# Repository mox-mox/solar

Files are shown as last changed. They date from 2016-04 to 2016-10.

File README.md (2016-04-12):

# solar

This repo will contain the files for a step-up converter board for powering my laptop from some solar cells.

Idea
====

Create a power supply that can power my laptop for off-grid use. To avoid having to re-charge the supply and avoid charge limits, use solar cells*. The panel should be foldable in some way to be portable when hiking.

*: Additional bonus: When I have to turn the display backlight higher on [very] bright days, the solar cells will also produce more energy.

Specification
-------------
Board:
 - Input: ca. 6-15V, up to 10A DC from solar cells or a battery AND 20V from a Thinkpad power plug*.
 - Output0: 20V, 2.5A OR 3.0A Voltage for Thinkpad
 - Output1: 5V, 1.5A for charging my mobile phone
 - Output2: 3.3V, 2A for supplying miscellaneous electronic devices [optional]
 - Output4: Battery charger for lead acid car starter battery [optional] AND/OR charging circuit for a lithium polymer battery.

Power supply:
 - Use 16 highly efficient soloar cells of 15 by 15 centimeters, yielding about 9V at 1 to 6A
 - The cell array should be foldable in some way to allow handy transportation in a backpack

Case:
 - The case should hold the converter board and provide a protected space for the solar cells for transportation
 - Target size is about 16 by 20 by 5 centimeters
 - Will probably be made of steel sheets for maximum protection

Connectors:
 - Power connector for the solar cells or battery
 - Thinkpad compatible receptable to attach a Thinkpad power plug.
 - Thinkpad compatible power plug to supply the Laptop
 - Some USB ports to charge USB-devices
 - A multi-plug with exchangable tips for all kinds of devices
 - Pinheaders providing 3.3V

*The 20V will be looped through with the voltage regulator for output0 disabled. This way, the board can still provide the low-voltage outputs.

Soldering QFN and VSON packages
-------------------------------
 - The outer QFN 'pins' can be soldered from the outside, pre-tinning the pads and using [lots of] flux
 - The bottom pad will be soldered from below, unsing the thermal vias that are anyways needed. For that purpose, the solder resist mask is removed from these vias.
 - See: https://www.youtube.com/watch?v=d-f-SBC0GrU

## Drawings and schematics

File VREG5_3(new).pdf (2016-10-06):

## WEBENCH ® Design Report

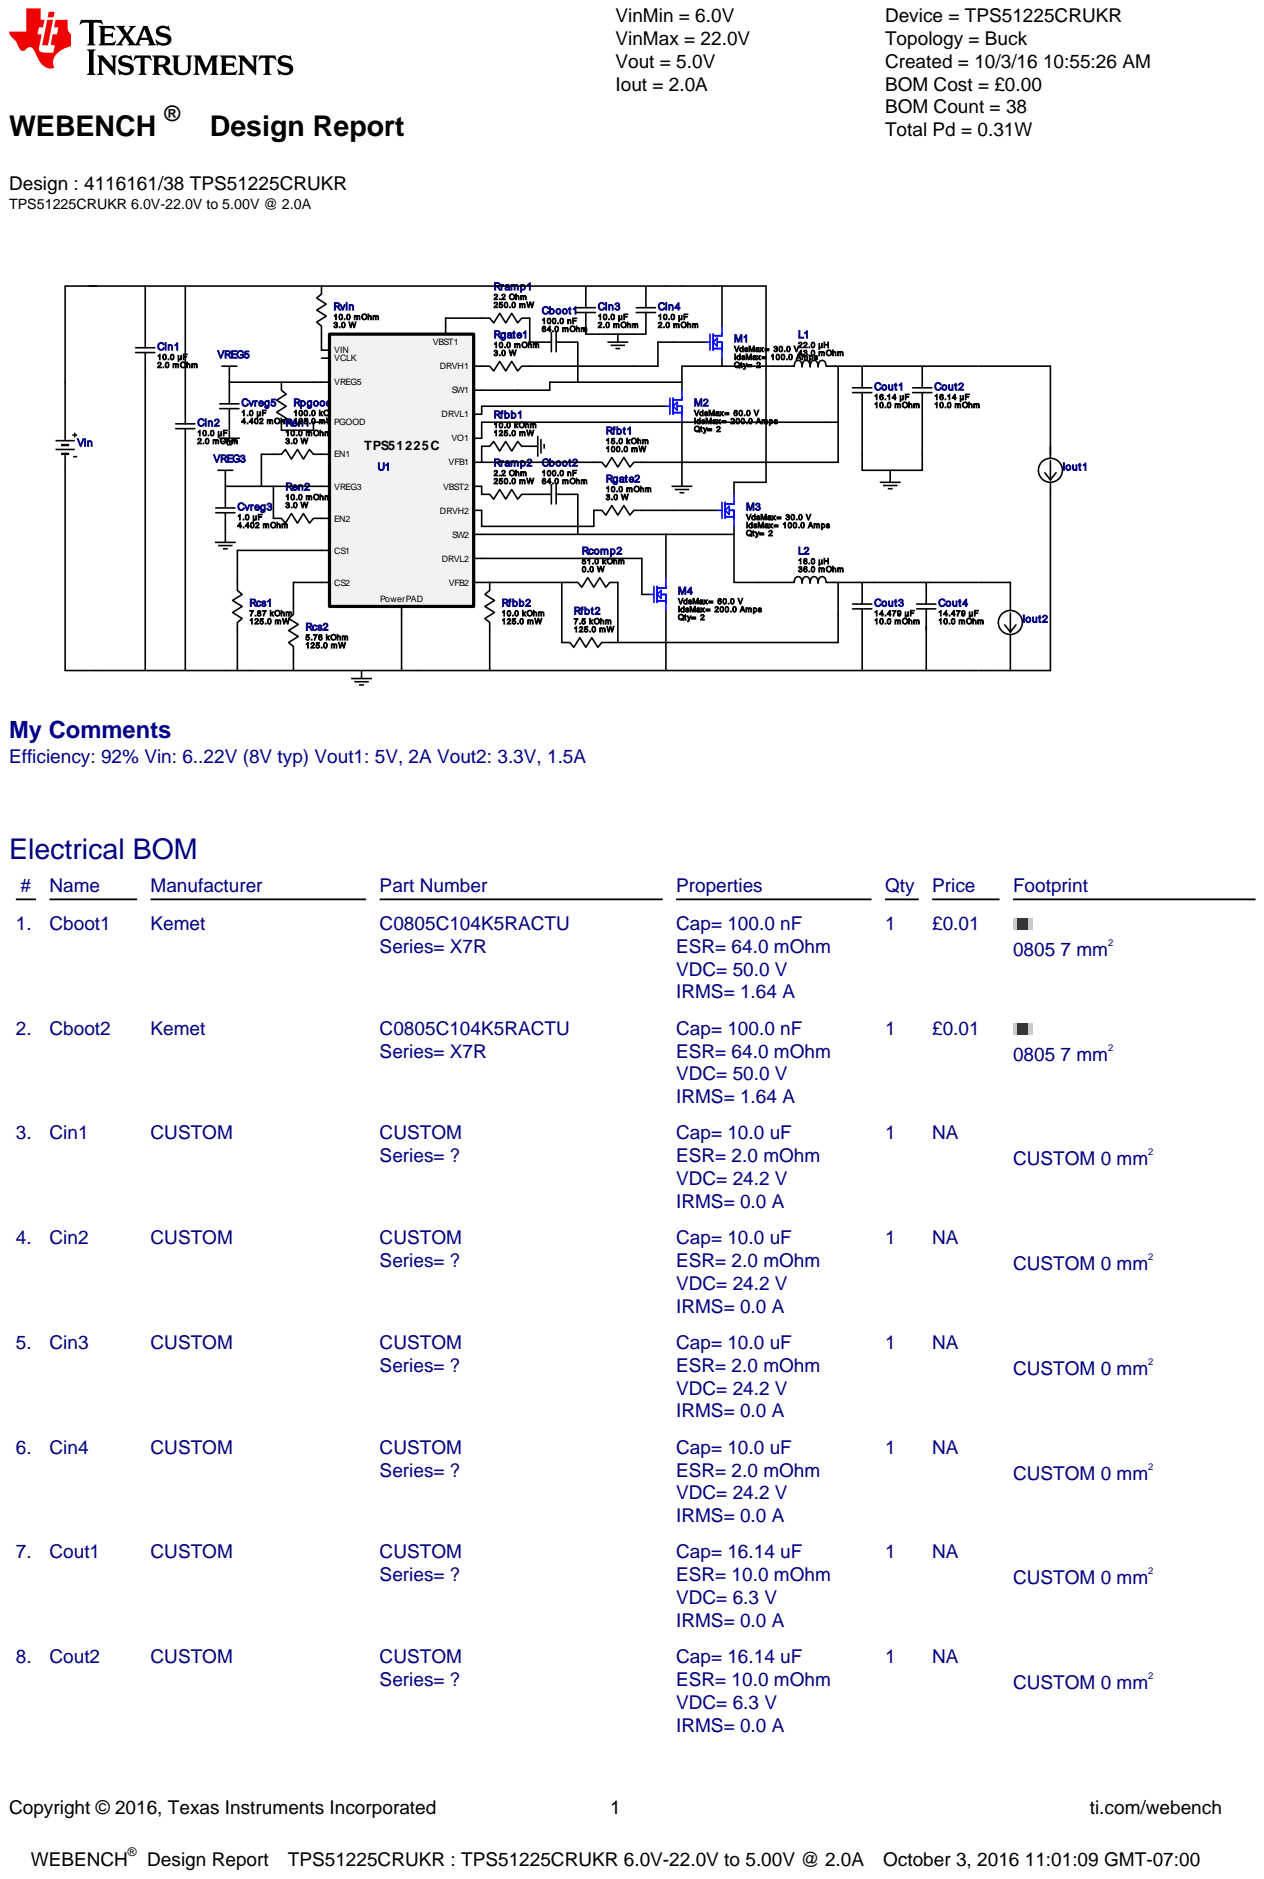
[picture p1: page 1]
Copyright © 2016, Texas Instruments Incorporated; ti.com/webench; WEBENCH®; Design : 4116161/38 TPS51225CRUKR TPS51225CRUKR 6.0V-22.0V to 5.00V @ 2.0A; VinMin = 6.0V VinMax = 22.0V Vout = 5.0V Iout = 2.0A; Device = TPS51225CRUKR Topology = Buck Created = 10/3/16 10:55:26 AM BOM Cost = £0.00 BOM Count = 38 Total Pd = 0.31W; Cboot1 100.0 nF 64.0 mOhm; Cboot2 100.0 nF 64.0 mOhm; Cin1 10.0 µF 2.0 mOhm; Cin2 10.0 µF 2.0 mOhm; Cin3 10.0 µF 2.0 mOhm; Cin4 10.0 µF 2.0 mOhm; Cout1 16.14 µF 10.0 mOhm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

My Comments
Efficiency: 92% Vin: 6..22V (8V typ) Vout1: 5V, 2A Vout2: 3.3V, 1.5A

Design Report TPS51225CRUKR : TPS51225CRUKR 6.0V-22.0V to 5.00V @ 2.0A October 3, 2016 11:01:09 GMT-07:00

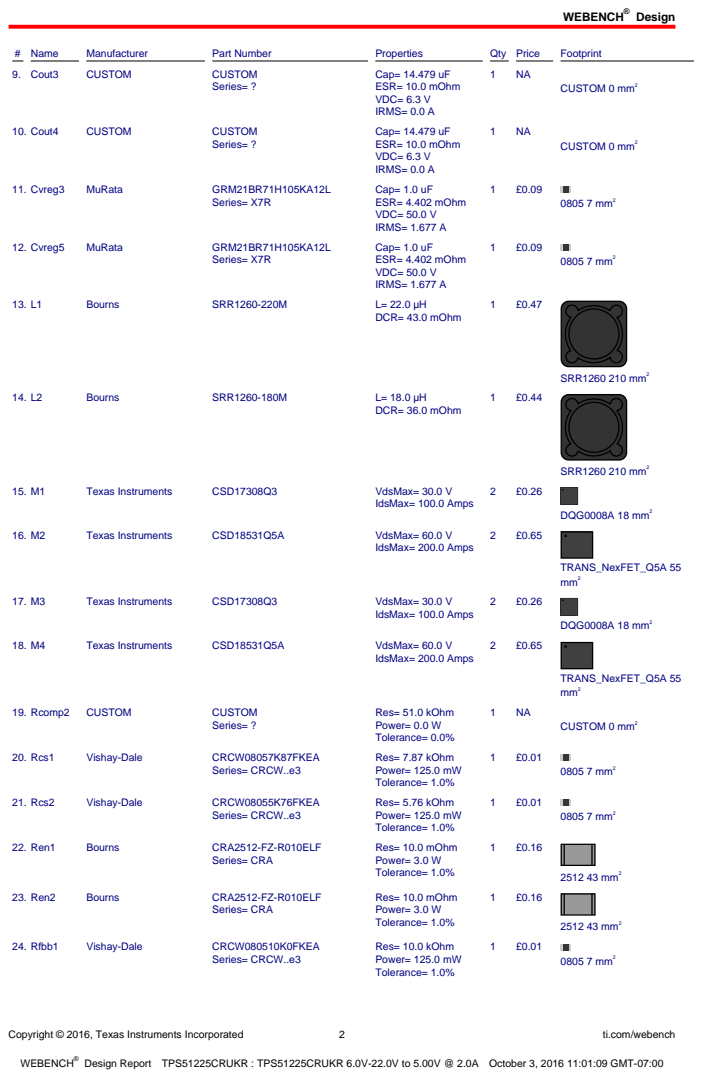
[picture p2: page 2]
Design; Copyright © 2016, Texas Instruments Incorporated; ti.com/webench; # Name; Manufacturer; Part Number; Properties; Qty Price; Footprint; 9. Cout3; CUSTOM; Series= ?; Cap= 14.479 uF ESR= 10.0 mOhm VDC= 6.3 V IRMS= 0.0 A; CUSTOM 0 mm²; 10. Cout4; 11. Cvreg3; MuRata; GRM21BR71H105KA12L; Series= X7R; Cap= 1.0 uF ESR= 4.402 mOhm VDC= 50.0 V IRMS= 1.677 A; 0805 7 mm²; 12. Cvreg5; Bourns; SRR1260-220M; DCR= 43.0 mOhm; SRR1260 210 mm²; SRR1260-180M; DCR= 36.0 mOhm; Texas Instruments; CSD17308Q3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

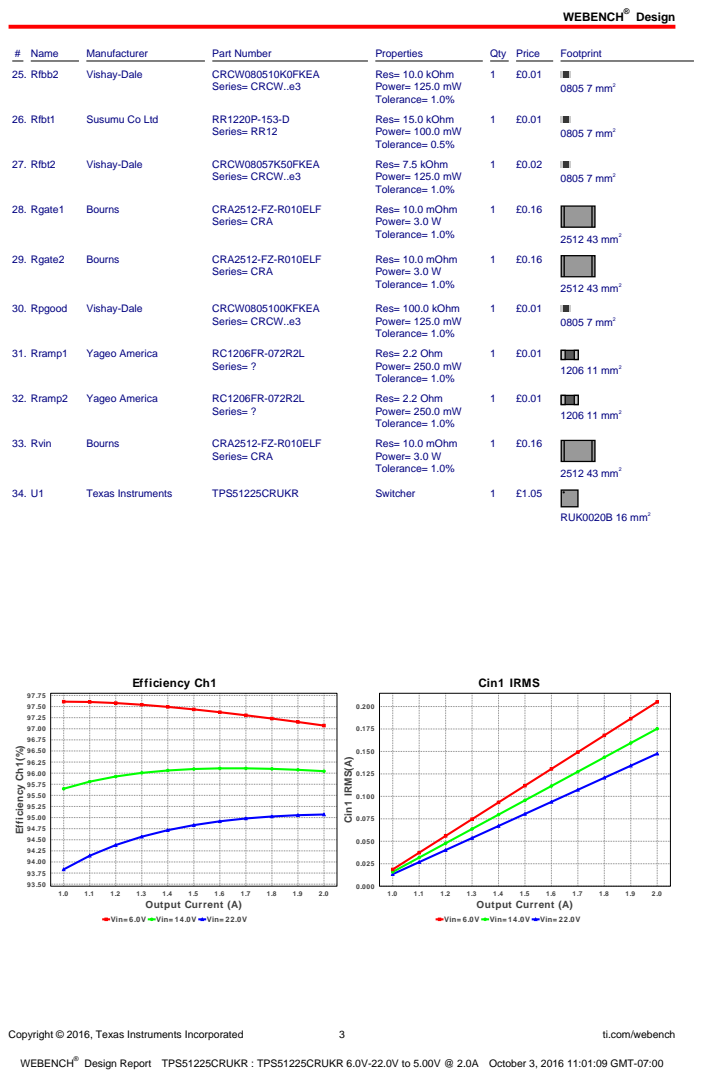
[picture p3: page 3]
Copyright © 2016, Texas Instruments Incorporated; ti.com/webench; # Name; Manufacturer; Part Number; Properties; Qty Price; Footprint; 25. Rfbb2; Vishay-Dale; CRCW080510K0FKEA; Series= CRCW..e3; Res= 10.0 kOhm Power= 125.0 mW Tolerance= 1.0%; 0805 7 mm²; 26. Rfbt1; Susumu Co Ltd; Series= RR12; Res= 15.0 kOhm Power= 100.0 mW Tolerance= 0.5%; 27. Rfbt2; CRCW08057K50FKEA; Res= 7.5 kOhm Power= 125.0 mW Tolerance= 1.0%; 28. Rgate1; Bourns; CRA2512-FZ-R010ELF; Series= CRA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

Vin= 6.0V Vin= 14.0V Vin= 22.0V

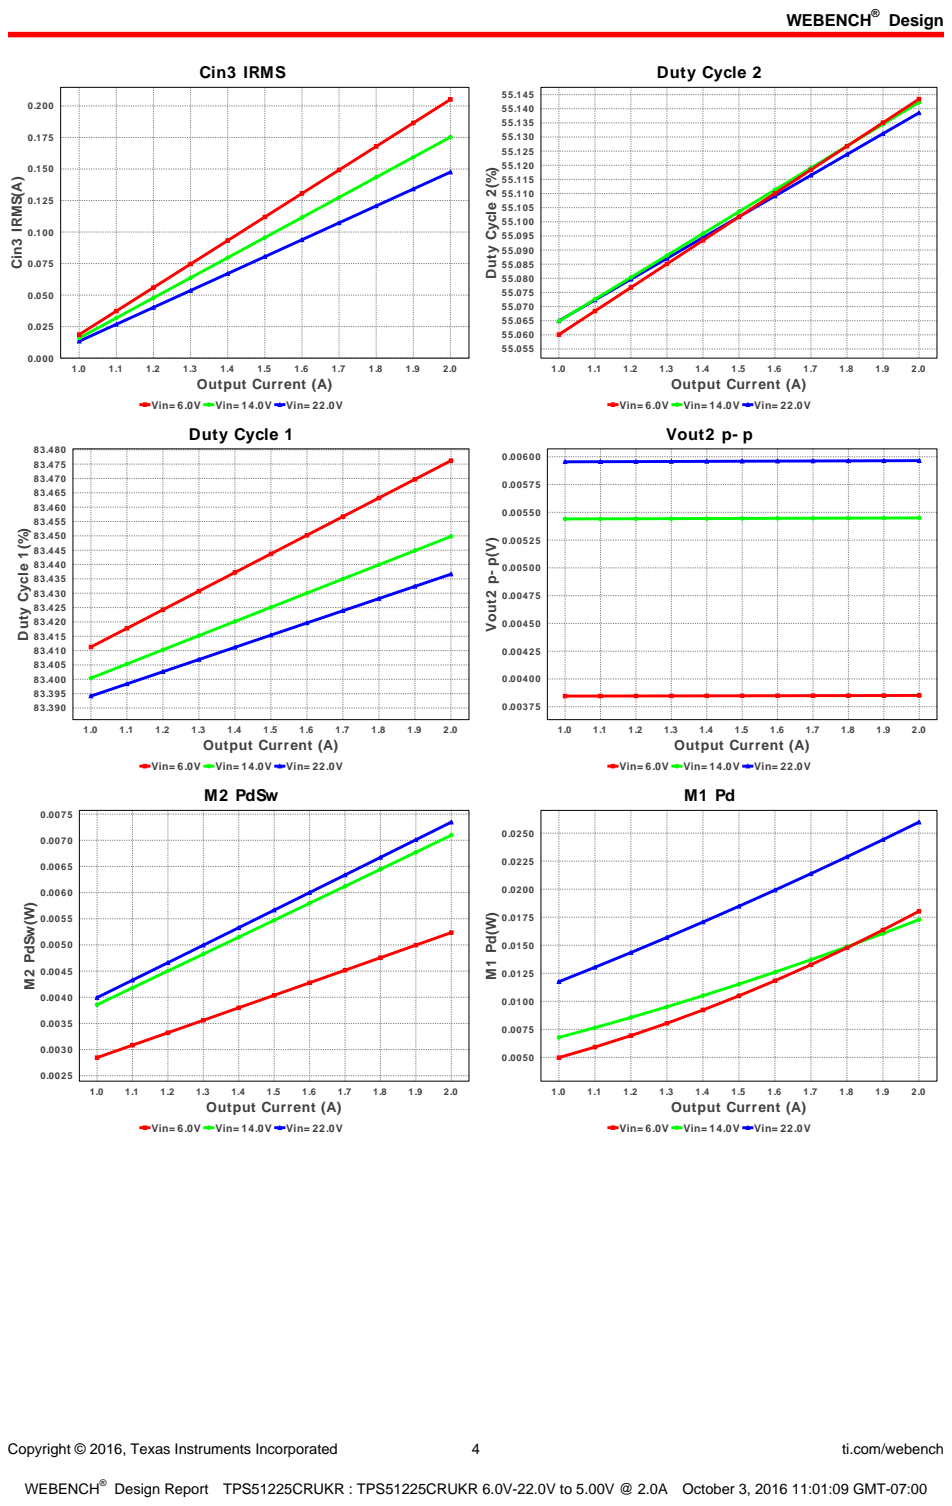
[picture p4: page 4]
Copyright © 2016, Texas Instruments Incorporated; ti.com/webench; Cin3 IRMS; 2.0 Output Current (A); Cin3 IRMS(A); Duty Cycle 2; Duty Cycle 2(%); Duty Cycle 1(%); Vout2 p- p(V); M2 PdSw(W)

Vin= 6.0V Vin= 14.0V Vin= 22.0V
Duty Cycle 1

Vout2 p- p

M2 PdSw

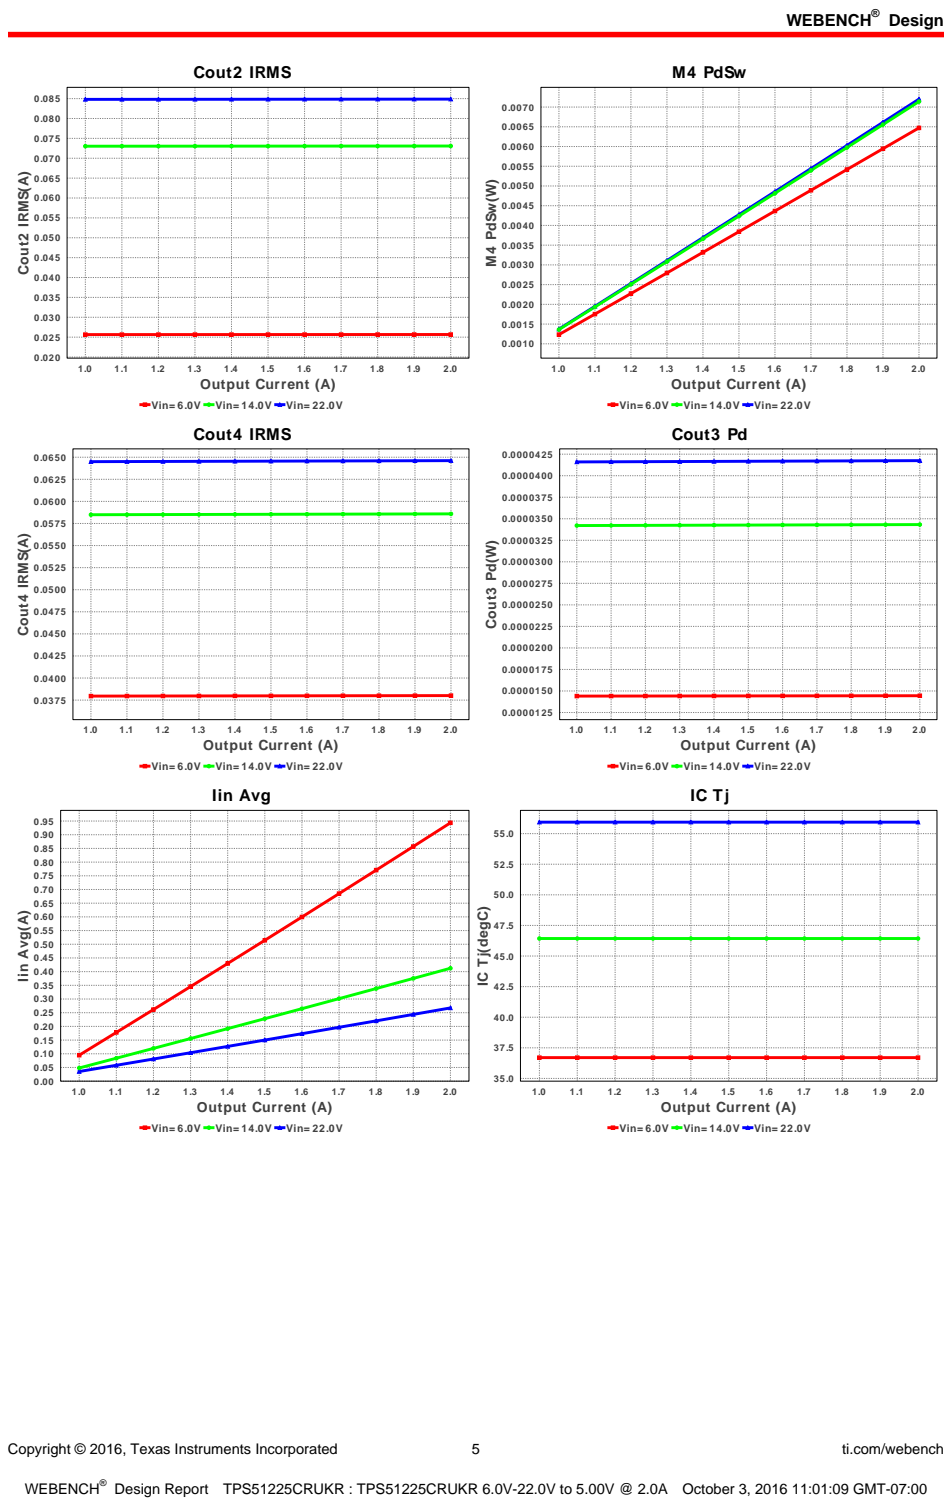
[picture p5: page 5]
Copyright © 2016, Texas Instruments Incorporated; ti.com/webench; Cout2 IRMS; 2.0 Output Current (A); Cout2 IRMS(A); M4 PdSw; M4 PdSw(W); Cout4 IRMS(A); Cout3 Pd(W); Iin Avg; Iin Avg(A)

Vin= 6.0V Vin= 14.0V Vin= 22.0V
Cout4 IRMS

Cout3 Pd

IC Tj(degC)

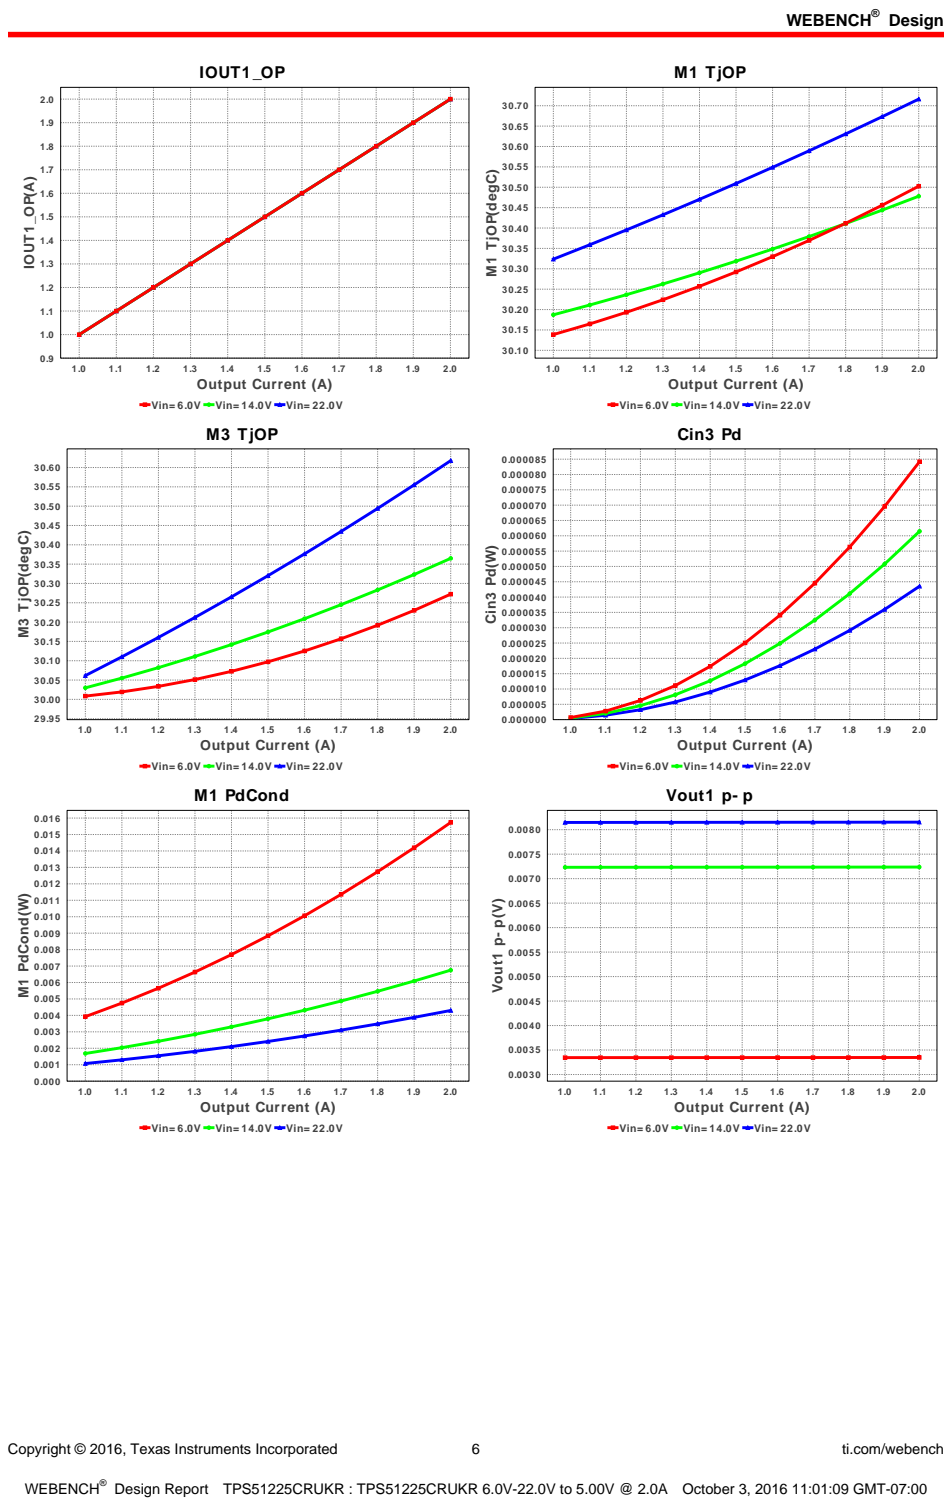
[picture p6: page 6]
Copyright © 2016, Texas Instruments Incorporated; ti.com/webench; IOUT1_OP; 2.0 Output Current (A); IOUT1_OP(A); M1 TjOP; M1 TjOP(degC); M3 TjOP(degC); Cin3 Pd; Cin3 Pd(W); M1 PdCond(W); Vout1 p- p(V)

Vin= 6.0V Vin= 14.0V Vin= 22.0V
M3 TjOP

M1 PdCond

Vout1 p- p

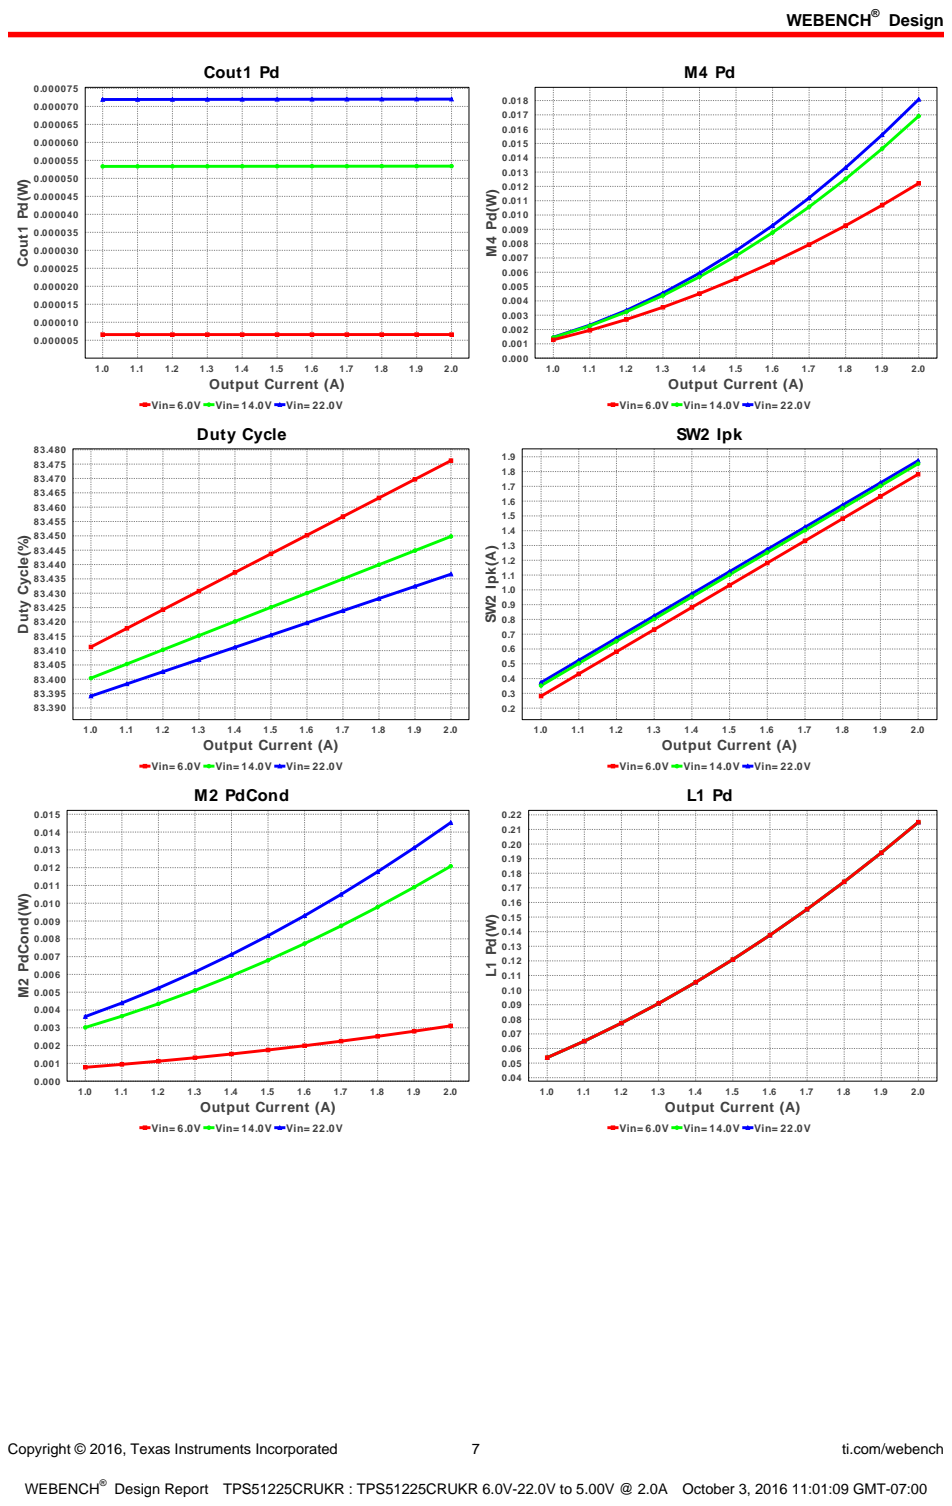
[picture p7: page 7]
Copyright © 2016, Texas Instruments Incorporated; ti.com/webench; Cout1 Pd; 2.0 Output Current (A); Cout1 Pd(W); Duty Cycle(%); SW2 Ipk(A); M2 PdCond(W)

Vin= 6.0V Vin= 14.0V Vin= 22.0V
Duty Cycle

SW2 Ipk

M2 PdCond

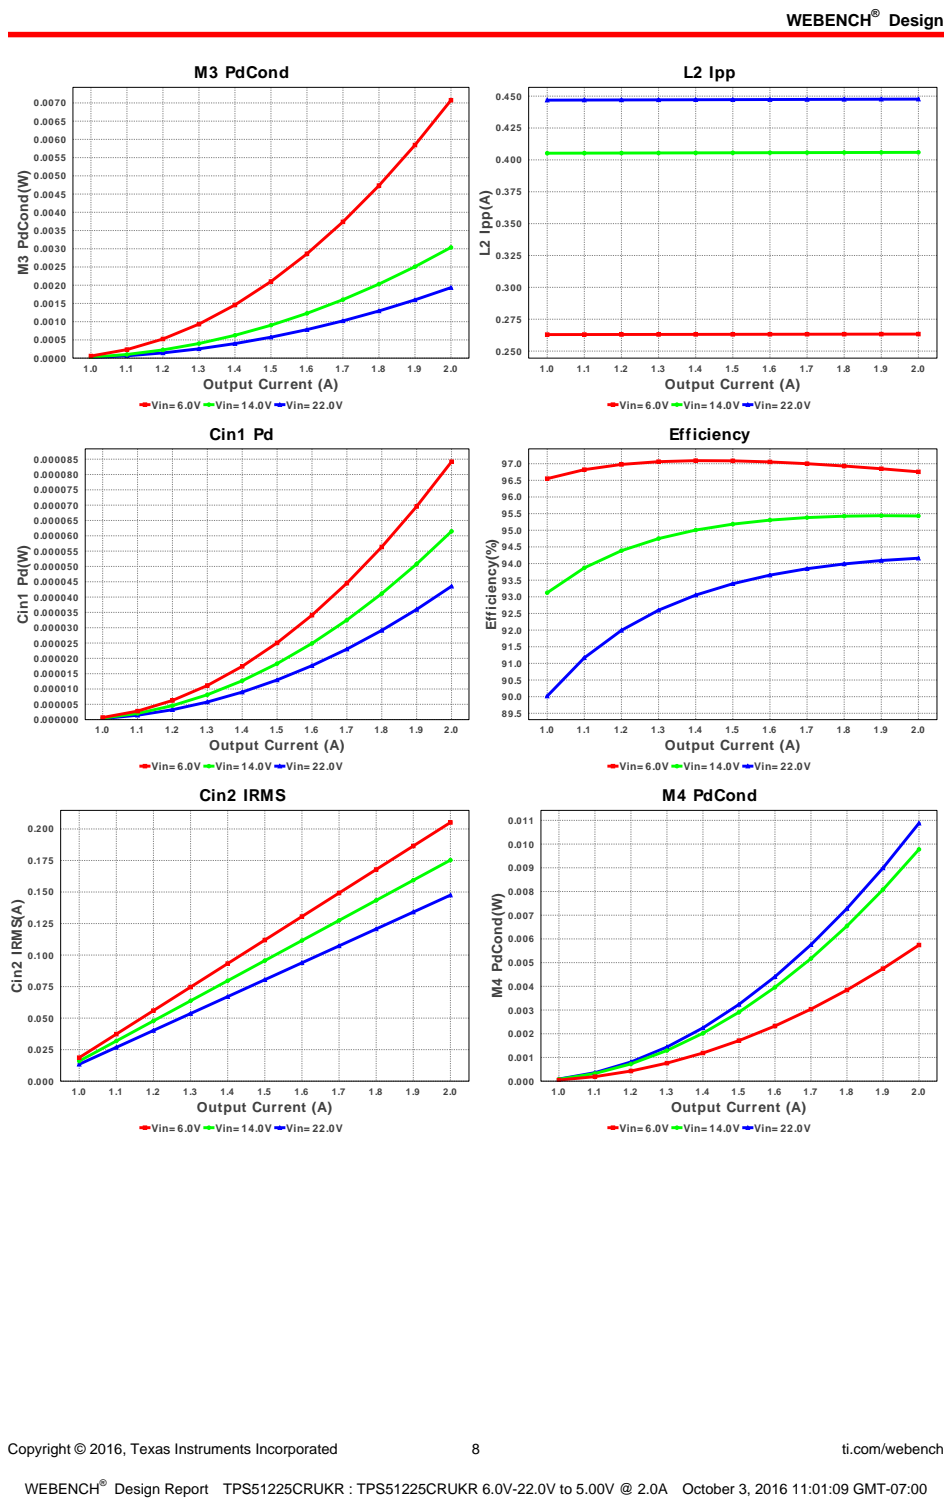
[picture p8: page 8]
Copyright © 2016, Texas Instruments Incorporated; ti.com/webench; M3 PdCond; 2.0 Output Current (A); M3 PdCond(W); L2 Ipp; L2 Ipp(A); Cin1 Pd; Cin1 Pd(W); Efficiency(%); Cin2 IRMS(A); M4 PdCond(W)

Vin= 6.0V Vin= 14.0V Vin= 22.0V

Efficiency

Cin2 IRMS

M4 PdCond

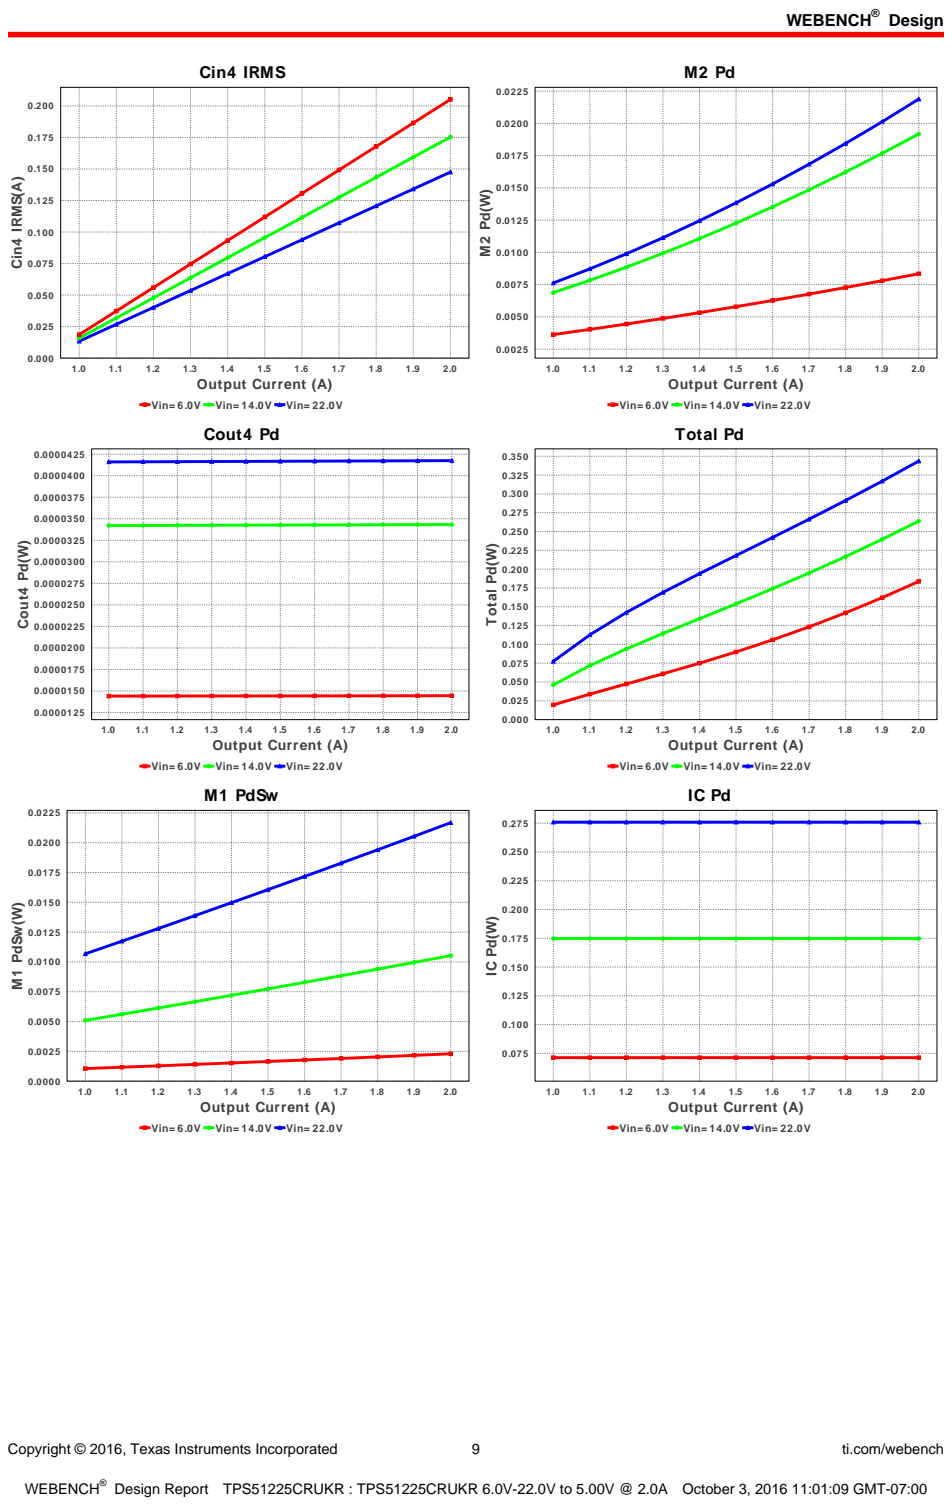
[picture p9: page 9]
Copyright © 2016, Texas Instruments Incorporated; ti.com/webench; Cin4 IRMS; 2.0 Output Current (A); Cin4 IRMS(A); Cout4 Pd(W); Total Pd(W); M1 PdSw(W)

Vin= 6.0V Vin= 14.0V Vin= 22.0V
Cout4 Pd

Total Pd

M1 PdSw

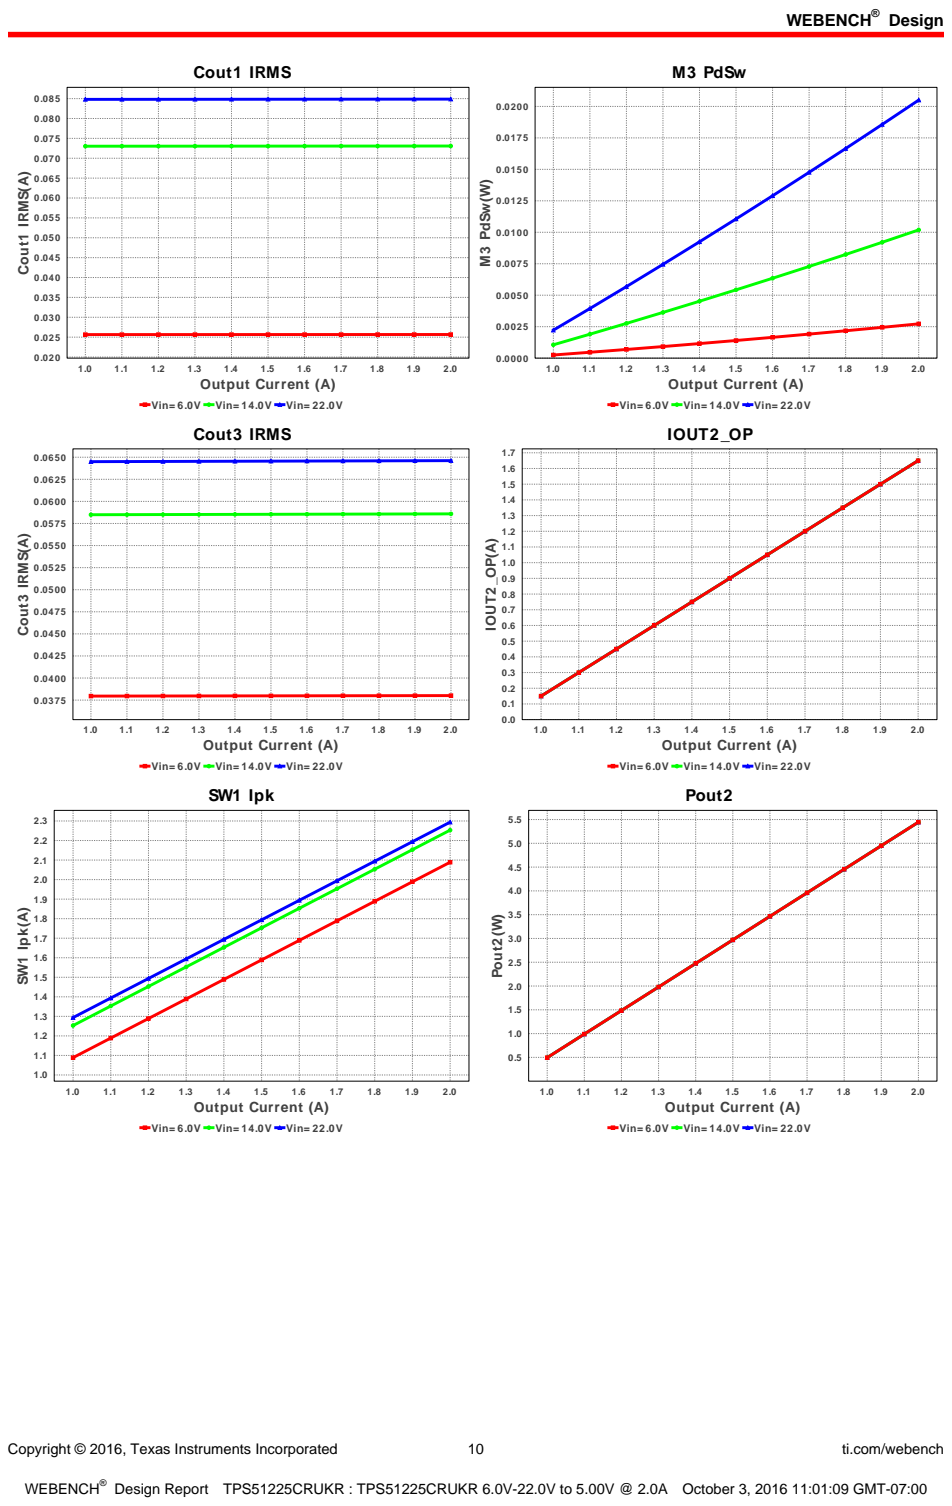
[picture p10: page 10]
Copyright © 2016, Texas Instruments Incorporated; ti.com/webench; Cout1 IRMS; 2.0 Output Current (A); Cout1 IRMS(A); M3 PdSw; M3 PdSw(W); Cout3 IRMS(A); IOUT2_OP(A); SW1 Ipk(A); Pout2; Pout2(W)

Vin= 6.0V Vin= 14.0V Vin= 22.0V
Cout3 IRMS

IOUT2_OP

SW1 Ipk

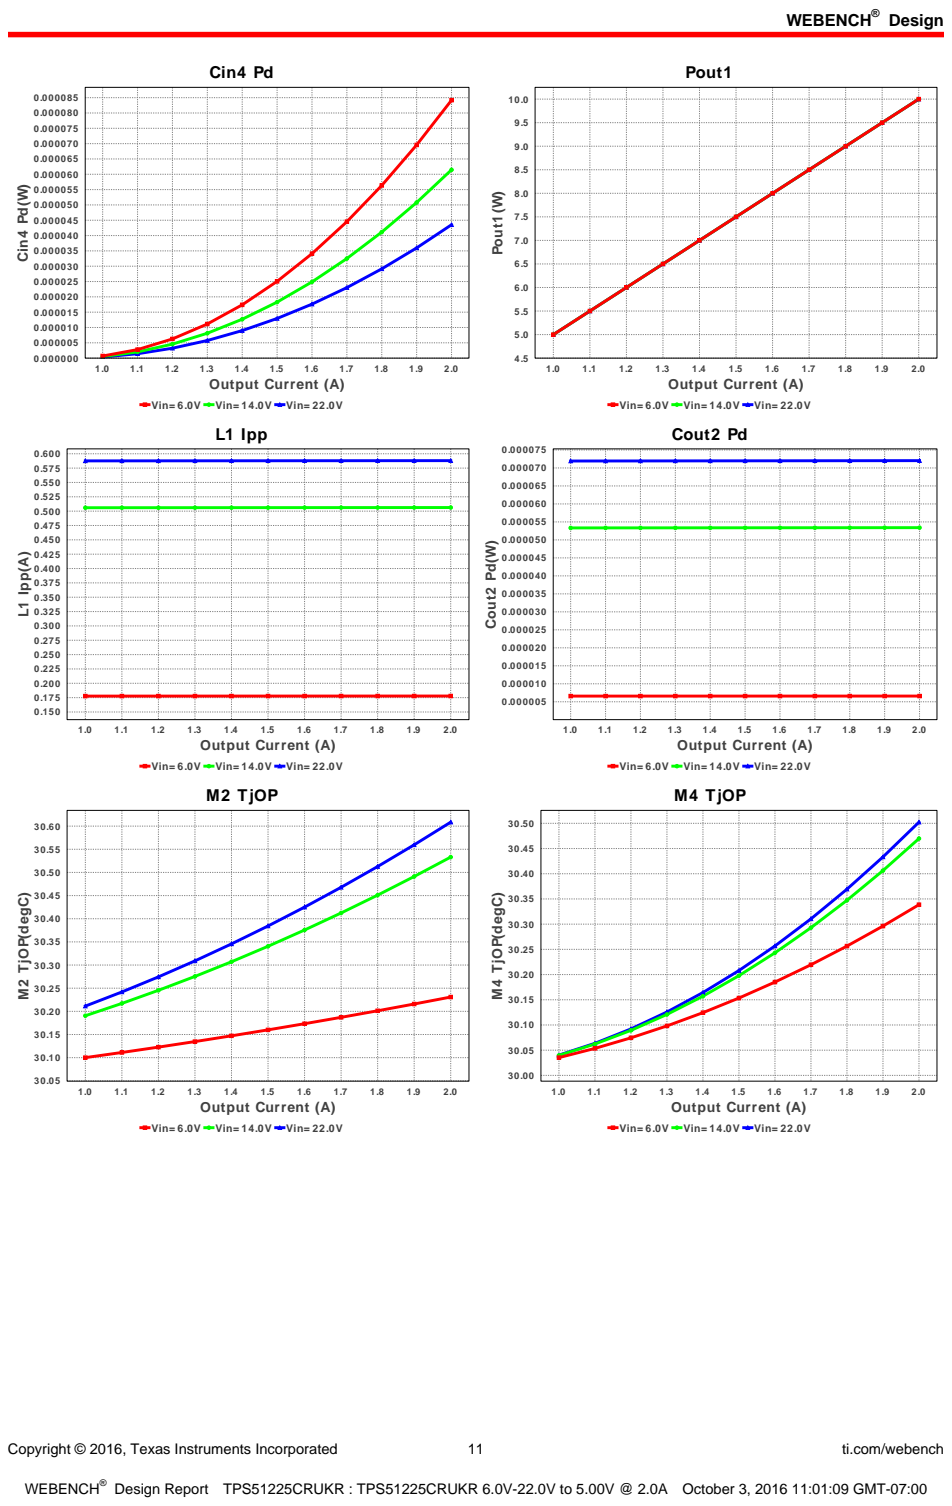
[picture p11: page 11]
Copyright © 2016, Texas Instruments Incorporated; ti.com/webench; Cin4 Pd; 2.0 Output Current (A); Cin4 Pd(W); Pout1; Pout1(W); L1 Ipp; L1 Ipp(A); Cout2 Pd(W); M2 TjOP(degC); M4 TjOP(degC)

Vin= 6.0V Vin= 14.0V Vin= 22.0V

Cout2 Pd

M2 TjOP

M4 TjOP

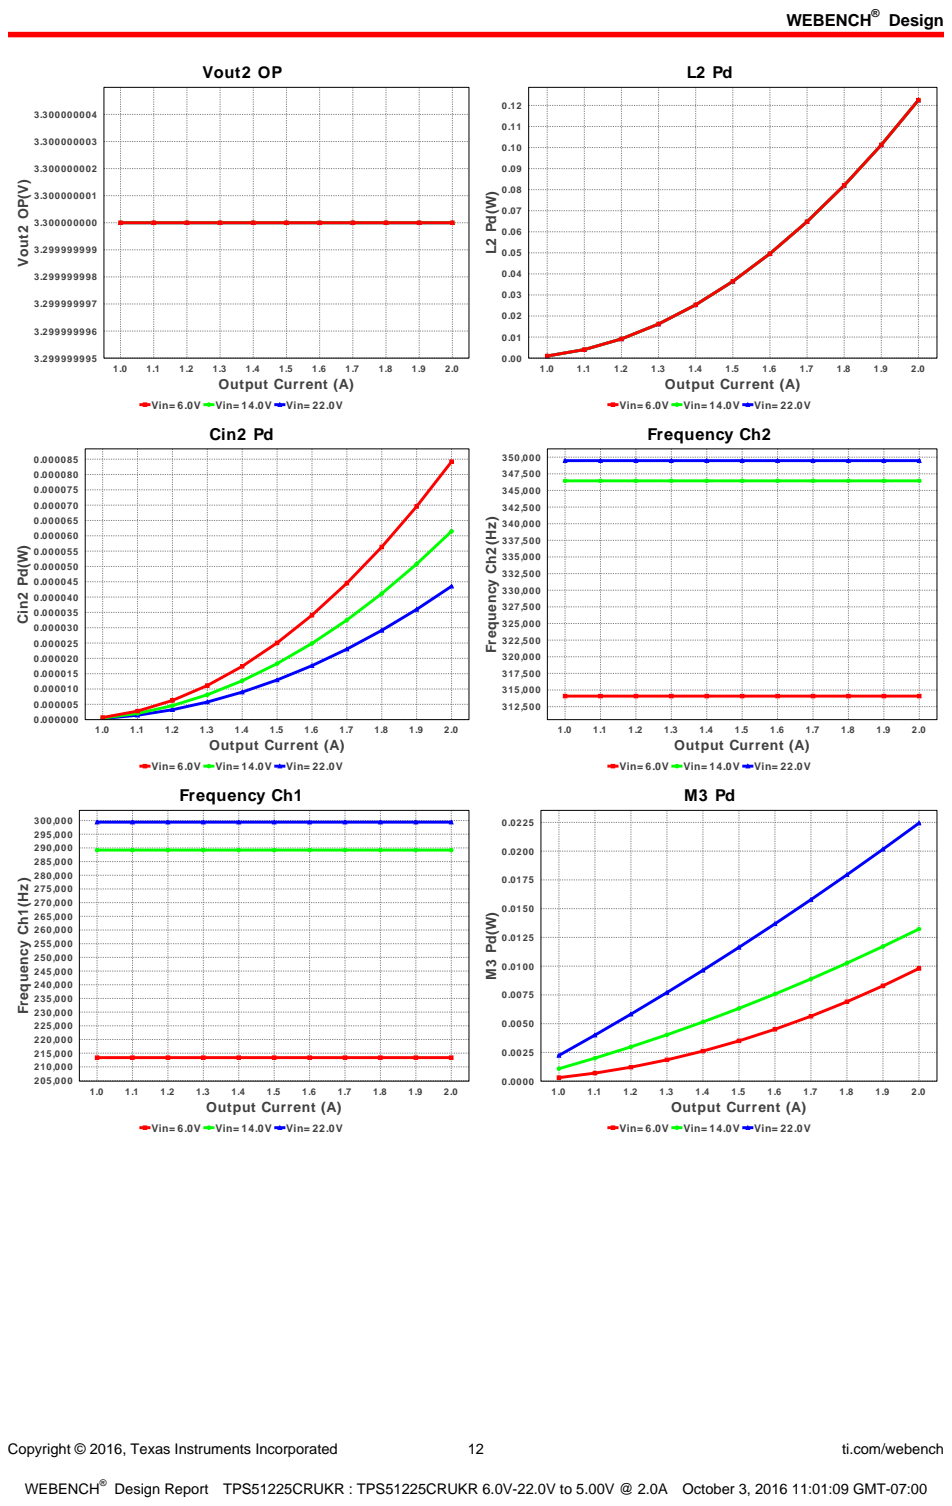
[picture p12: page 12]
Copyright © 2016, Texas Instruments Incorporated; ti.com/webench; Vout2 OP; 2.0 Output Current (A); Vout2 OP(V); Cin2 Pd; Cin2 Pd(W); Frequency Ch2(Hz); Frequency Ch1(Hz)

Vin= 6.0V Vin= 14.0V Vin= 22.0V

Frequency Ch2

Frequency Ch1
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

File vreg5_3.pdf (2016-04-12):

## WEBENCH ® Design Report


1. This regulator device is qualified for Automotive applications. All passives and other components selected in this design may not be qualified
for Automotive applications. The user is required to verify that all components in the design meet the qualification and safety requirements for
their specific application.View WEBENCH(R) Disclaimer.

Design Report LM25119PSQ/NOPB : LM25119PSQ/NOPB 6.0V-22.0V to 3.30V @ 2.0A April 12, 2016 07:38:07 GMT-07:00

Design; Copyright © 2016, Texas Instruments Incorporated; ti.com/webench; # Name; Manufacturer; Part Number; Properties; Qty Price; Footprint; 9. Cout_ch1 MuRata; GRM31CR60J107ME39L; Series= X5R; Cap= 100.0 uF ESR= 4.885 mOhm VDC= 6.3 V IRMS= 4.4118 A; 1206_190 11 mm²; 10. Cout_ch2 Panasonic; 6SVPE220M; Series= SVPE; Cap= 220.0 uF ESR= 10.0 mOhm VDC= 6.3 V IRMS= 3.9 A; CAPSMT_62_F61 74 mm²; 11. Cramp1; Yageo America; CC0805KRX7R9BB821; Series= X7R; Cap= 820.0 pF VDC= 50.0 V IRMS= 0.0 A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

Copyright © 2016, Texas Instruments Incorporated | 3 | ti.com/webench
# Name | Manufacturer | Part Number | Properties | Qty Price | Footprint

23. M2 | Texas Instruments | CSD18531Q5A (http://www.ti.com/lit/ds/symlink/csd18531q5a.pdf) | VdsMax= 60.0 V
IdsMax= 100.0 Amps

1 $0.90

TRANS_NexFET_Q5A 55
mm²
24. M3 | Texas Instruments | CSD17308Q3 (http://www.ti.com/lit/ds/symlink/csd17308q3.pdf) | VdsMax= 30.0 V
IdsMax= 47.0 Amps

1 $0.34

TRANS_NexFET_Q3 18
mm²
25. M4 | Texas Instruments | CSD18532Q5B (http://www.ti.com/lit/ds/symlink/csd18532q5b.pdf) | VdsMax= 60.0 V
IdsMax= 100.0 Amps

1 $1.14

TRANS_NexFET_Q5B 58
mm²
26. Rcomp1 | Panasonic | ERJ-6ENF2492V (http://www.panasonic.com/industrial/components/pdf/AOA0000CE2.pdf)
Series= ERJ-6E

Res= 24.9 kOhm
Power= 125.0 mW
Tolerance= 1.0%

1 $0.01
0805 7 mm²
27. Rcomp2 | Panasonic | ERJ-6ENF1242V (http://www.panasonic.com/industrial/components/pdf/AOA0000CE2.pdf)
Series= ERJ-6E

Res= 12.4 kOhm
Power= 125.0 mW
Tolerance= 1.0%

1 $0.01
0805 7 mm²
28. Rfb1 | Panasonic | ERJ-6ENF1151V (http://www.panasonic.com/industrial/components/pdf/AOA0000CE2.pdf)
Series= ERJ-6E

Res= 1.15 kOhm
Power= 125.0 mW
Tolerance= 1.0%

1 $0.01
0805 7 mm²
29. Rfb2 | Panasonic | ERJ-6ENF6041V (http://www.panasonic.com/industrial/components/pdf/AOA0000CE2.pdf)
Series= ERJ-6E

Res= 6.04 kOhm
Power= 125.0 mW
Tolerance= 1.0%

1 $0.01
0805 7 mm²
30. Rfb3 | Panasonic | ERJ-6ENF1151V (http://www.panasonic.com/industrial/components/pdf/AOA0000CE2.pdf)
Series= ERJ-6E

Res= 1.15 kOhm
Power= 125.0 mW
Tolerance= 1.0%

1 $0.01
0805 7 mm²
31. Rfb4 | Susumu Co Ltd | RR1220P-362-D (http://www.susumu.co.jp/english/pdf/products%2Dj01%2D04.pdf)
Series= RR12

Res= 3.6 kOhm
Power= 100.0 mW
Tolerance= 0.5%

1 $0.01
0805 7 mm²
32. Rramp1 | Panasonic | ERJ-6ENF1003V (http://www.panasonic.com/industrial/components/pdf/AOA0000CE2.pdf)
Series= ERJ-6E

Res= 100.0 kOhm
Power= 125.0 mW
Tolerance= 1.0%

1 $0.01
0805 7 mm²
33. Rramp2 | Panasonic | ERJ-6ENF6492V (http://www.panasonic.com/industrial/components/pdf/AOA0000CE2.pdf)
Series= ERJ-6E

Res= 64.9 kOhm
Power= 125.0 mW
Tolerance= 1.0%

1 $0.01
0805 7 mm²
34. Rsense1 Panasonic | ERJ-L14KF33MU (http://www.panasonic.com/industrial/components/pdf/AOA0000CE3.pdf)
Series= ERJ-L14

Res= 33.0 mOhm
Power= 330.0 mW
Tolerance= 1.0%

1 $0.11
1210 15 mm²
35. Rsense2 Stackpole Electronics Inc CSR1206FK25L0 (http://www.seielect.com/Catalog/SEI%2Dcsr.pdf) Series= ?

Res= 25.0 mOhm
Power= 500.0 mW
Tolerance= 1.0%

1 $0.10
1206 11 mm²
36. Rt | Panasonic | ERJ-6ENF5112V (http://www.panasonic.com/industrial/components/pdf/AOA0000CE2.pdf)
Series= ERJ-6E

Res= 51.1 kOhm
Power= 125.0 mW
Tolerance= 1.0%

1 $0.01
0805 7 mm²
37. Ruv1 | Panasonic | ERJ-6ENF5492V (http://www.panasonic.com/industrial/components/pdf/AOA0000CE2.pdf)
Series= ERJ-6E

Res= 54.9 kOhm
Power= 125.0 mW
Tolerance= 1.0%

1 $0.01
0805 7 mm²
38. Ruv2 | Panasonic | ERJ-6ENF1912V (http://www.panasonic.com/industrial/components/pdf/AOA0000CE2.pdf)
Series= ERJ-6E

Res= 19.1 kOhm
Power= 125.0 mW
Tolerance= 1.0%

1 $0.01
0805 7 mm²
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

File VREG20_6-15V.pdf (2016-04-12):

## WEBENCH ® Design Report

Copyright © 2016, Texas Instruments Incorporated; ti.com/webench; WEBENCH®; Design : 4116161/21 TPS43060RTER TPS43060RTER 6.0V-15.0V to 20.00V @ 2.5A; VinMin = 6.0V VinMax = 15.0V Vout = 20.0V Iout = 2.5A; Device = TPS43060RTER Topology = Boost Created = 4/12/16 4:45:58 AM BOM Cost = $10.90 BOM Count = 28 Total Pd = 1.33W; C12 100.0 pF 119.0 mOhm; Cboot 220.0 nF; 16.0 mOhm; Ccomp 68.0 nF; Ccomp2 3.0 nF; Cin 22.0 µF 1.558 mOhm Qty= 3; Cout 33.0 µF; Qty= 3; Css 4.7 nF 600.0 mOhm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

Dboot VF@Io= 430.0 mV

1. The pulse skip mode in the device has not been modeled. Efficiency and operational parameters of the model in pulse skip mode is not valid.

Design Report TPS43060RTER : TPS43060RTER 6.0V-15.0V to 20.00V @ 2.5A April 12, 2016 04:46:46 GMT-07:00

Design

Copyright © 2016, Texas Instruments Incorporated | 2 | ti.com/webench
# Name | Manufacturer | Part Number | Properties | Qty Price | Footprint

9. Cvin | AVX | 08053C104KAT2A (http://www.avx.com/docs/masterpubs/smccp.pdf) Series= X7R | Cap= 100.0 nF ESR= 280.0 mOhm VDC= 25.0 V IRMS= 0.0 A
1 | $0.01
| | | | | 0805 7 mm²
10. Dboot | ON Semiconductor | MBRS2040LT3G (http://www.onsemi.com/pub%5Flink/Collateral/MBRS2040LT3%2DD.PDF) | VF@Io= 430.0 mV VRRM= 40.0 V
1 | $0.12

SMB 44 mm²
11. L1 | Coilcraft | SER2915H-153KL (http://www.coilcraft.com/pdfs/ser2900.pdf) | L= 15.0 µH DCR= 1.9 mOhm
1 | $1.95

SER2915H 652 mm²
12. M1 | Texas Instruments | CSD17506Q5A (http://www.ti.com/lit/ds/symlink/csd17506q5a.pdf) | VdsMax= 30.0 V IdsMax= 100.0 Amps | 1 | $0.50

TRANS_NexFET_Q5A 55
mm²
13. M2 | Texas Instruments | CSD17577Q5A (http://www.ti.com/lit/ds/symlink/csd17577q5a.pdf) | VdsMax= 30.0 V IdsMax= 22.0 Amps | 1 | $0.30

TRANS_NexFET_Q5A 55
mm²
14. R13 | Vishay-Dale | CRCW080510R0FKEA (http://www.vishay.com/docs/20035/dcrcwe3.pdf) Series= CRCW..e3 | Res= 10.0 Ohm Power= 125.0 mW Tolerance= 1.0% | 1 | $0.01
0805 7 mm²
15. R14 | Vishay-Dale | CRCW080510R0FKEA (http://www.vishay.com/docs/20035/dcrcwe3.pdf) Series= CRCW..e3 | Res= 10.0 Ohm Power= 125.0 mW Tolerance= 1.0% | 1 | $0.01
0805 7 mm²
16. R19 | Vishay-Dale | CRCW08052R00FKEA (http://www.vishay.com/docs/20035/dcrcwe3.pdf) Series= CRCW..e3 | Res= 2.0 Ohm Power= 125.0 mW Tolerance= 1.0% | 1 | $0.01
0805 7 mm²
17. Rcomp | Panasonic | ERJ-6ENF4221V (http://www.panasonic.com/industrial/components/pdf/AOA0000CE2.pdf) Series= ERJ-6E | Res= 4.22 kOhm Power= 125.0 mW Tolerance= 1.0% | 1 | $0.01
0805 7 mm²
18. Rfbb | Vishay-Dale | CRCW040211K0FKED (http://www.vishay.com/docs/20035/dcrcwe3.pdf) Series= CRCW..e3 | Res= 11.0 kOhm Power= 63.0 mW Tolerance= 1.0% | 1 | $0.01
0402 3 mm²
19. Rfbt | Vishay-Dale | CRCW0402169KFKED (http://www.vishay.com/docs/20035/dcrcwe3.pdf) Series= CRCW..e3 | Res= 169.0 kOhm Power= 63.0 mW Tolerance= 1.0% | 1 | $0.01
0402 3 mm²
20. Rpg | Panasonic | ERJ-6ENF1003V (http://www.panasonic.com/industrial/components/pdf/AOA0000CE2.pdf) Series= ERJ-6E | Res= 100.0 kOhm Power= 125.0 mW Tolerance= 1.0% | 1 | $0.01
0805 7 mm²
21. Rsns1 | Susumu Co Ltd | PRL1632-R009-F-T1 (http://www.susumu%2Dusa.com/pdf/PRL%5FRL%5FData%5Fsheet.pdf) Series= PRL1632 | Res= 9.0 mOhm Power= 1.0 W Tolerance= 1.0% | 1 | $0.19

0612 11 mm²

22. Rsns2 | Susumu Co Ltd | PRL1632-R009-F-T1 (http://www.susumu%2Dusa.com/pdf/PRL%5FRL%5FData%5Fsheet.pdf) Series= PRL1632 | Res= 9.0 mOhm Power= 1.0 W Tolerance= 1.0% | 1 | $0.19

0612 11 mm²

23. Rt | Panasonic | ERJ-6ENF2873V (http://www.panasonic.com/industrial/components/pdf/AOA0000CE2.pdf) Series= ERJ-6E | Res= 287.0 kOhm Power= 125.0 mW Tolerance= 1.0% | 1 | $0.01
0805 7 mm²
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

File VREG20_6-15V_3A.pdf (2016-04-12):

## WEBENCH ® Design Report

Copyright © 2016, Texas Instruments Incorporated; ti.com/webench; WEBENCH®; Design : 4116161/22 TPS43060RTER TPS43060RTER 6.0V-15.0V to 20.00V @ 3.0A; VinMin = 6.0V VinMax = 15.0V Vout = 20.0V Iout = 3.0A; Device = TPS43060RTER Topology = Boost Created = 4/12/16 5:37:01 AM BOM Cost = $8.69 BOM Count = 28 Total Pd = 1.94W; C12 100.0 pF 119.0 mOhm; Cboot 220.0 nF; 16.0 mOhm; Ccomp 68.0 nF; Ccomp2 3.3 nF; Cin 22.0 µF 1.558 mOhm Qty= 4; Cout 68.0 µF; 20.0 mOhm Qty= 2; Css 4.7 nF 600.0 mOhm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

Dboot VF@Io= 440.0 mV

1. The pulse skip mode in the device has not been modeled. Efficiency and operational parameters of the model in pulse skip mode is not valid.

Design Report TPS43060RTER : TPS43060RTER 6.0V-15.0V to 20.00V @ 3.0A April 12, 2016 05:37:43 GMT-07:00

Design

Copyright © 2016, Texas Instruments Incorporated | 2 | ti.com/webench
# Name | Manufacturer | Part Number | Properties | Qty Price | Footprint

9. Cvin | AVX | 08053C104KAT2A (http://www.avx.com/docs/masterpubs/smccp.pdf) Series= X7R | Cap= 100.0 nF ESR= 280.0 mOhm VDC= 25.0 V IRMS= 0.0 A
1 | $0.01
| | | | | 0805 7 mm²
10. Dboot | Vishay-Semiconductor | SL23-E3/52T (http://www.vishay.com/docs/88741/88741.pdf) | VF@Io= 440.0 mV VRRM= 30.0 V
1 | $0.21

SMB 44 mm²
11. L1 | Coilcraft | SER2915H-153KL (http://www.coilcraft.com/pdfs/ser2900.pdf) | L= 15.0 µH DCR= 1.9 mOhm
1 | $1.95

SER2915H 652 mm²
12. M1 | Texas Instruments | CSD17506Q5A (http://www.ti.com/lit/ds/symlink/csd17506q5a.pdf) | VdsMax= 30.0 V IdsMax= 100.0 Amps | 1 | $0.50

TRANS_NexFET_Q5A 55
mm²
13. M2 | Texas Instruments | CSD17577Q5A (http://www.ti.com/lit/ds/symlink/csd17577q5a.pdf) | VdsMax= 30.0 V IdsMax= 22.0 Amps | 1 | $0.30

TRANS_NexFET_Q5A 55
mm²
14. R13 | Vishay-Dale | CRCW080510R0FKEA (http://www.vishay.com/docs/20035/dcrcwe3.pdf) Series= CRCW..e3 | Res= 10.0 Ohm Power= 125.0 mW Tolerance= 1.0% | 1 | $0.01
0805 7 mm²
15. R14 | Vishay-Dale | CRCW080510R0FKEA (http://www.vishay.com/docs/20035/dcrcwe3.pdf) Series= CRCW..e3 | Res= 10.0 Ohm Power= 125.0 mW Tolerance= 1.0% | 1 | $0.01
0805 7 mm²
16. R19 | Vishay-Dale | CRCW08052R00FKEA (http://www.vishay.com/docs/20035/dcrcwe3.pdf) Series= CRCW..e3 | Res= 2.0 Ohm Power= 125.0 mW Tolerance= 1.0% | 1 | $0.01
0805 7 mm²
17. Rcomp | Panasonic | ERJ-6ENF5111V (http://www.panasonic.com/industrial/components/pdf/AOA0000CE2.pdf) Series= ERJ-6E | Res= 5.11 kOhm Power= 125.0 mW Tolerance= 1.0% | 1 | $0.01
0805 7 mm²
18. Rfbb | Vishay-Dale | CRCW040211K0FKED (http://www.vishay.com/docs/20035/dcrcwe3.pdf) Series= CRCW..e3 | Res= 11.0 kOhm Power= 63.0 mW Tolerance= 1.0% | 1 | $0.01
0402 3 mm²
19. Rfbt | Vishay-Dale | CRCW0402169KFKED (http://www.vishay.com/docs/20035/dcrcwe3.pdf) Series= CRCW..e3 | Res= 169.0 kOhm Power= 63.0 mW Tolerance= 1.0% | 1 | $0.01
0402 3 mm²
20. Rpg | Panasonic | ERJ-6ENF1003V (http://www.panasonic.com/industrial/components/pdf/AOA0000CE2.pdf) Series= ERJ-6E | Res= 100.0 kOhm Power= 125.0 mW Tolerance= 1.0% | 1 | $0.01
0805 7 mm²
21. Rsns1 | Rohm | PMR100HZPFU8L00 (http://media.digikey.com/pdf/Data%20Sheets/Rohm%20PDFs/PMR25%2DSeries.pdf) Series= PMR100 | Res= 8.0 mOhm Power= 2.0 W Tolerance= 1.0% | 1 | $0.16

2512 43 mm²
22. Rsns2 | Rohm | PMR100HZPFU8L00 (http://media.digikey.com/pdf/Data%20Sheets/Rohm%20PDFs/PMR25%2DSeries.pdf) Series= PMR100 | Res= 8.0 mOhm Power= 2.0 W Tolerance= 1.0% | 1 | $0.16

2512 43 mm²
23. Rt | Panasonic | ERJ-6ENF2873V (http://www.panasonic.com/industrial/components/pdf/AOA0000CE2.pdf) Series= ERJ-6E | Res= 287.0 kOhm Power= 125.0 mW Tolerance= 1.0% | 1 | $0.01
0805 7 mm²
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

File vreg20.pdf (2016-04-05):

## WEBENCH ® Design Report

Copyright © 2016, Texas Instruments Incorporated; ti.com/webench; WEBENCH®; Design : 4116161/14 TPS43060RTER TPS43060RTER 6.0V-12.0V to 20.00V @ 2.5A; VinMin = 6.0V VinMax = 12.0V Vout = 20.0V Iout = 2.5A; Device = TPS43060RTER Topology = Boost Created = 3/11/16 5:39:49 AM BOM Cost = $11.86 BOM Count = 30 Total Pd = 1.33W; C12 100.0 pF 119.0 mOhm; Cboot 220.0 nF; 16.0 mOhm; Ccomp 68.0 nF; Ccomp2 3.0 nF; Cin 22.0 µF 1.558 mOhm Qty= 5; Cout 33.0 µF; Qty= 3; Css 4.7 nF 600.0 mOhm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

Dboot VF@Io= 430.0 mV

1. The pulse skip mode in the device has not been modeled. Efficiency and operational parameters of the model in pulse skip mode is not valid.
My Comments

Design Report TPS43060RTER : TPS43060RTER 6.0V-12.0V to 20.00V @ 2.5A March 11, 2016 05:41:30 GMT-08:00

Design

Copyright © 2016, Texas Instruments Incorporated | 2 | ti.com/webench
# Name | Manufacturer | Part Number | Properties | Qty Price | Footprint

9. Cvin | AVX | 08053C104KAT2A (http://www.avx.com/docs/masterpubs/smccp.pdf) Series= X7R | Cap= 100.0 nF ESR= 280.0 mOhm VDC= 25.0 V IRMS= 0.0 A
1 | $0.01
| | | | | 0805 7 mm²
10. Dboot | ON Semiconductor | MBRS2040LT3G (http://www.onsemi.com/pub%5Flink/Collateral/MBRS2040LT3%2DD.PDF) | VF@Io= 430.0 mV VRRM= 40.0 V
1 | $0.12

SMB 44 mm²
11. L1 | Coilcraft | SER2915H-153KL (http://www.coilcraft.com/pdfs/ser2900.pdf) | L= 15.0 µH DCR= 1.9 mOhm
1 | $1.95

SER2915H 652 mm²
12. M1 | Texas Instruments | CSD17506Q5A (http://www.ti.com/lit/ds/symlink/csd17506q5a.pdf) | VdsMax= 30.0 V IdsMax= 100.0 Amps | 1 | $0.50

TRANS_NexFET_Q5A 55
mm²
13. M2 | Texas Instruments | CSD17577Q5A (http://www.ti.com/lit/ds/symlink/csd17577q5a.pdf) | VdsMax= 30.0 V IdsMax= 22.0 Amps | 1 | $0.30

TRANS_NexFET_Q5A 55
mm²
14. R13 | Vishay-Dale | CRCW080510R0FKEA (http://www.vishay.com/docs/20035/dcrcwe3.pdf) Series= CRCW..e3 | Res= 10.0 Ohm Power= 125.0 mW Tolerance= 1.0% | 1 | $0.01
0805 7 mm²
15. R14 | Vishay-Dale | CRCW080510R0FKEA (http://www.vishay.com/docs/20035/dcrcwe3.pdf) Series= CRCW..e3 | Res= 10.0 Ohm Power= 125.0 mW Tolerance= 1.0% | 1 | $0.01
0805 7 mm²
16. R19 | Vishay-Dale | CRCW08052R00FKEA (http://www.vishay.com/docs/20035/dcrcwe3.pdf) Series= CRCW..e3 | Res= 2.0 Ohm Power= 125.0 mW Tolerance= 1.0% | 1 | $0.01
0805 7 mm²
17. Rcomp | Panasonic | ERJ-6ENF4221V (http://www.panasonic.com/industrial/components/pdf/AOA0000CE2.pdf) Series= ERJ-6E | Res= 4.22 kOhm Power= 125.0 mW Tolerance= 1.0% | 1 | $0.01
0805 7 mm²
18. Rfbb | Vishay-Dale | CRCW040211K0FKED (http://www.vishay.com/docs/20035/dcrcwe3.pdf) Series= CRCW..e3 | Res= 11.0 kOhm Power= 63.0 mW Tolerance= 1.0% | 1 | $0.01
0402 3 mm²
19. Rfbt | Vishay-Dale | CRCW0402169KFKED (http://www.vishay.com/docs/20035/dcrcwe3.pdf) Series= CRCW..e3 | Res= 169.0 kOhm Power= 63.0 mW Tolerance= 1.0% | 1 | $0.01
0402 3 mm²
20. Rpg | Panasonic | ERJ-6ENF1003V (http://www.panasonic.com/industrial/components/pdf/AOA0000CE2.pdf) Series= ERJ-6E | Res= 100.0 kOhm Power= 125.0 mW Tolerance= 1.0% | 1 | $0.01
0805 7 mm²
21. Rsns1 | Susumu Co Ltd | PRL1632-R009-F-T1 (http://www.susumu%2Dusa.com/pdf/PRL%5FRL%5FData%5Fsheet.pdf) Series= PRL1632 | Res= 9.0 mOhm Power= 1.0 W Tolerance= 1.0% | 1 | $0.19

0612 11 mm²

22. Rsns2 | Susumu Co Ltd | PRL1632-R009-F-T1 (http://www.susumu%2Dusa.com/pdf/PRL%5FRL%5FData%5Fsheet.pdf) Series= PRL1632 | Res= 9.0 mOhm Power= 1.0 W Tolerance= 1.0% | 1 | $0.19

0612 11 mm²

23. Rt | Panasonic | ERJ-6ENF2873V (http://www.panasonic.com/industrial/components/pdf/AOA0000CE2.pdf) Series= ERJ-6E | Res= 287.0 kOhm Power= 125.0 mW Tolerance= 1.0% | 1 | $0.01
0805 7 mm²
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

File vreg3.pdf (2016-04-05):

## WEBENCH ® Design Report

Copyright © 2016, Texas Instruments Incorporated; ti.com/webench; WEBENCH®; Design : 4116161/15 LM3150MH/NOPB LM3150MH/NOPB 6.0V-12.0V to 3.30V @ 1.5A; VinMin = 6.0V VinMax = 12.0V Vout = 3.3V Iout = 1.5A; Device = LM3150MH/NOPB Topology = Buck Created = 3/11/16 6:49:28 AM BOM Cost = $4.49 BOM Count = 16 Total Pd = 0.17W; Cff 2.2 nF 400.0 mOhm; Cbst 470.0 nF; Cbyp 100.0 nF 280.0 mOhm; Cin 22.0 µF 2.0 mOhm Qty= 2; Cout 100.0 µF 40.0 mOhm; Css 15.0 nF; Cvcc 1.0 µF; L1 47.0 µH 21.0 mOhm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

Design Report LM3150MH/NOPB : LM3150MH/NOPB 6.0V-12.0V to 3.30V @ 1.5A March 11, 2016 06:51:17 GMT-08:00

Design; Copyright © 2016, Texas Instruments Incorporated; ti.com/webench; # Name; Manufacturer; Part Number; Properties; Qty Price; Footprint; Coilcraft; SER1390-473MLB; DCR= 21.0 mOhm; SER1390 240 mm²; Texas Instruments; CSD17307Q5A; VdsMax= 30.0 V; IdsMax= 73.0 Amps; TRANS_NexFET_Q5A 55 mm²; CSD16321Q5; VdsMax= 25.0 V; IdsMax= 100.0 Amps; TRANS_NexFET_Q5 55 mm²; 11. Rfb1; Panasonic; ERJ-6ENF1002V; Series= ERJ-6E; Res= 10.0 kOhm Power= 125.0 mW Tolerance= 1.0%; 0805 7 mm²; 12. Rfb2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

IC Tj(degC)

Vin= 6.0V Vin= 9.0V Vin= 12.0V
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

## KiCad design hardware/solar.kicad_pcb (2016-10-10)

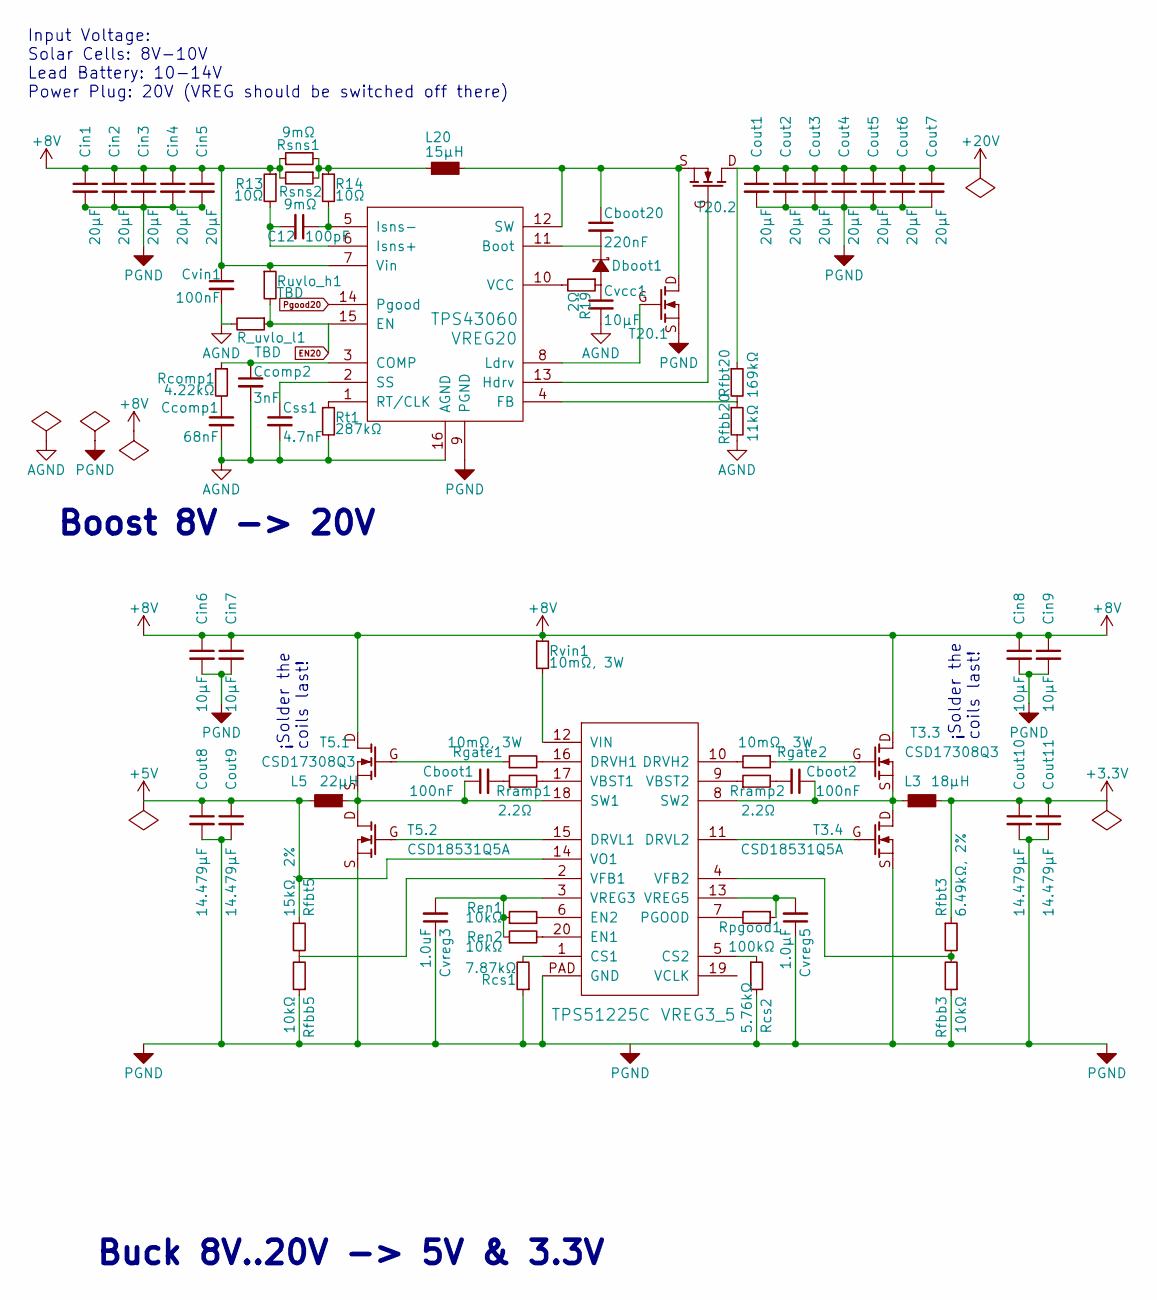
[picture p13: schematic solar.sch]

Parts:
C12: 100pF; C_0603_HandSoldering
Cboot1, Cboot2: 100nF; C_0603_HandSoldering
Cboot20: 220nF; C_0603_HandSoldering
Ccomp1: 68nF; C_0603_HandSoldering
Ccomp2: 3nF; C_0603_HandSoldering
Cin1, Cin2, Cin3, Cin4, Cin5: 20µF; C_1210_HandSoldering
Cin6, Cin7, Cin8, Cin9: 10µF; C_1210_HandSoldering
Cout1, Cout2, Cout3, Cout4, Cout5, Cout6, Cout7: 20µF; C_1210_HandSoldering
Cout8, Cout9, Cout10, Cout11: 14.479µF; C_1210_HandSoldering
Css1: 4.7nF; C_0603_HandSoldering
Cvcc1: 10µF; C_0805_HandSoldering
Cvin1: 100nF; C_0603_HandSoldering
Cvreg3: 1.0uF; C_0603_HandSoldering
Cvreg5: 1.0µF; C_0603_HandSoldering
Dboot1: ON Semiconductor MBRS2040LT3G; SMB_Handsoldering
L3: 18µH; Bourns_SRR1260_Series
L5: 22µH; Bourns_SRR1260_Series
L20: 15µH; Coilcraft_SER2900_Series
R13, R14: 10Ω; R_0603_HandSoldering
R19: 2Ω; R_0603_HandSoldering
R_uvlo_l1: TBD; R_0603_HandSoldering
Rcomp1: 4.22kΩ; R_0603_HandSoldering
Rcs1: 7.87kΩ; R_0603_HandSoldering
Rcs2: 5.76kΩ; R_0603_HandSoldering
Ren1, Ren2: 10kΩ; R_0603_HandSoldering
Rfbb3, Rfbb5: 10kΩ; R_0603_HandSoldering
Rfbb20: 11kΩ; R_0603_HandSoldering
Rfbt3: 6.49kΩ, 2%; R_0603_HandSoldering
Rfbt5: 15kΩ, 2%; R_0603_HandSoldering
Rfbt20: 169kΩ; R_0603_HandSoldering
Rgate1, Rgate2: 10mΩ, 3W; R_0603_HandSoldering
Rpgood1: 100kΩ; R_0603_HandSoldering
Rramp1, Rramp2: 2.2Ω; R_0603_HandSoldering
Rsns1, Rsns2: 9mΩ; R_1206_HandSoldering
Rt1: 287kΩ; R_0603_HandSoldering
Ruvlo_h1: TBD; R_0603_HandSoldering
Rvin1: 10mΩ, 3W; R_0805_HandSoldering
T3.3, T5.1: CSD17308Q3; VSON8_33x33
T3.4, T5.2: CSD18531Q5A; VSON8_50x60
T20.1: CSD17506Q5A; VSON8_50x60
T20.2: CSD17577Q5A; VSON8_50x60
VREG3_5: TPS51225C; QFN-20-1EP_3x3mm_Pitch0.4mm
VREG20: TPS43060; QFN-16-1EP_3x3mm_Pitch0.5mm

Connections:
+3V3: Cout10.1, Cout11.1, L3.2, Rfbt3.1
+5V: Cout8.1, Cout9.1, L5.2, Rfbt5.1, VREG3_5.14 (VO1)
+8V: Cin1.1, Cin2.1, Cin3.1, Cin4.1, Cin5.1, Cin6.1, Cin7.1, Cin8.1, Cin9.1, Cvin1.1, R13.1, Rsns1.1, Rsns2.2, Ruvlo_h1.1, Rvin1.1, T3.3.D, T5.1.D, VREG20.7 (Vin)
+20V: Cout1.1, Cout2.1, Cout3.1, Cout4.1, Cout5.1, Cout6.1, Cout7.1, Rfbt20.1, T20.2.D
AGND: Ccomp1.2, Ccomp2.2, Css1.2, Cvcc1.2, Cvin1.2, R_uvlo_l1.2, Rfbb20.2, Rt1.2, VREG20.16 (AGND), VREG20.17 (PowerPad)
EN20: R_uvlo_l1.1, Ruvlo_h1.2, VREG20.15 (EN)
unnamed: C12.1, R14.2, VREG20.5 (Isns-)
unnamed: C12.2, R13.2, VREG20.6 (Isns+)
unnamed: Cboot1.1, L5.1, T5.1.S, T5.2.D, VREG3_5.18 (SW1)
unnamed: Cboot1.2, Rramp1.1
unnamed: Cboot2.1, L3.1, T3.3.S, T3.4.D, VREG3_5.8 (SW2)
unnamed: Cboot2.2, Rramp2.2
unnamed: Cboot20.1, L20.2, T20.1.D, T20.2.S, VREG20.12 (SW)
unnamed: Cboot20.2, Dboot1.C, VREG20.11 (Boot)
unnamed: Ccomp1.1, Rcomp1.2
unnamed: Ccomp2.1, Rcomp1.1, VREG20.3 (COMP)
unnamed: Css1.1, VREG20.2 (SS)
unnamed: Cvcc1.1, Dboot1.A, R19.1
unnamed: Cvreg3.2, Ren1.1, Ren2.1, VREG3_5.3 (VREG3)
unnamed: Cvreg5.2, Rpgood1.1, VREG3_5.13 (VREG5)
unnamed: L20.1, R14.1, Rsns1.2, Rsns2.1
unnamed: R19.2, VREG20.10 (VCC)
unnamed: Rcs1.2, VREG3_5.1 (CS1)
unnamed: Rcs2.1, VREG3_5.5 (CS2)
unnamed: Ren1.2, VREG3_5.6 (EN2)
unnamed: Ren2.2, VREG3_5.20 (EN1)
unnamed: Rfbb3.2, Rfbt3.2, VREG3_5.4 (VFB2)
unnamed: Rfbb5.2, Rfbt5.2, VREG3_5.2 (VFB1)
unnamed: Rfbb20.1, Rfbt20.2, VREG20.4 (FB)
unnamed: Rgate1.1, T5.1.G
unnamed: Rgate1.2, VREG3_5.16 (DRVH1)
unnamed: Rgate2.1, T3.3.G
unnamed: Rgate2.2, VREG3_5.10 (DRVH2)
unnamed: Rpgood1.2, VREG3_5.7 (PGOOD)
unnamed: Rramp1.2, VREG3_5.17 (VBST1)
unnamed: Rramp2.1, VREG3_5.9 (VBST2)
unnamed: Rt1.1, VREG20.1 (RT/CLK)
unnamed: Rvin1.2, VREG3_5.12 (VIN)
unnamed: T3.4.G, VREG3_5.11 (DRVL2)
unnamed: T5.2.G, VREG3_5.15 (DRVL1)
unnamed: T20.1.G, VREG20.8 (Ldrv)
unnamed: T20.2.G, VREG20.13 (Hdrv)
PGND: Cin1.2, Cin2.2, Cin3.2, Cin4.2, Cin5.2, Cin6.2, Cin7.2, Cin8.2, Cin9.2, Cout1.2, Cout2.2, Cout3.2, Cout4.2, Cout5.2, Cout6.2, Cout7.2, Cout8.2, Cout9.2, Cout10.2, Cout11.2, Cvreg3.1, Cvreg5.1, Rcs1.1, Rcs2.2, Rfbb3.1, Rfbb5.1, T3.4.S, T5.2.S, T20.1.S, VREG3_5.PAD (GND), VREG20.9 (PGND)
Pgood20: VREG20.14 (Pgood)

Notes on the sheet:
Boost 8V -> 20V
Input Voltage: Solar Cells: 8V-10V Lead Battery: 10-14V Power Plug: 20V (VREG should be switched off there)
Buck 8V..20V -> 5V & 3.3V
¡Solder the coils last!

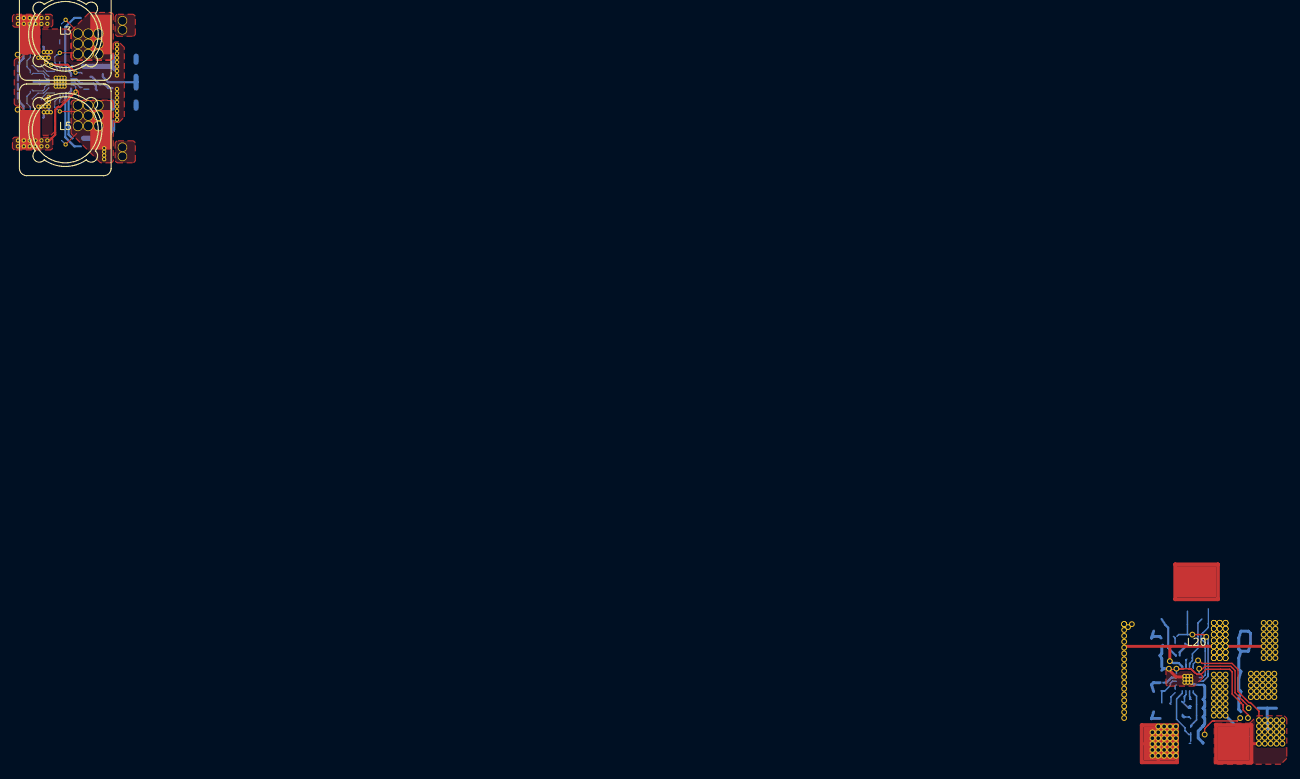
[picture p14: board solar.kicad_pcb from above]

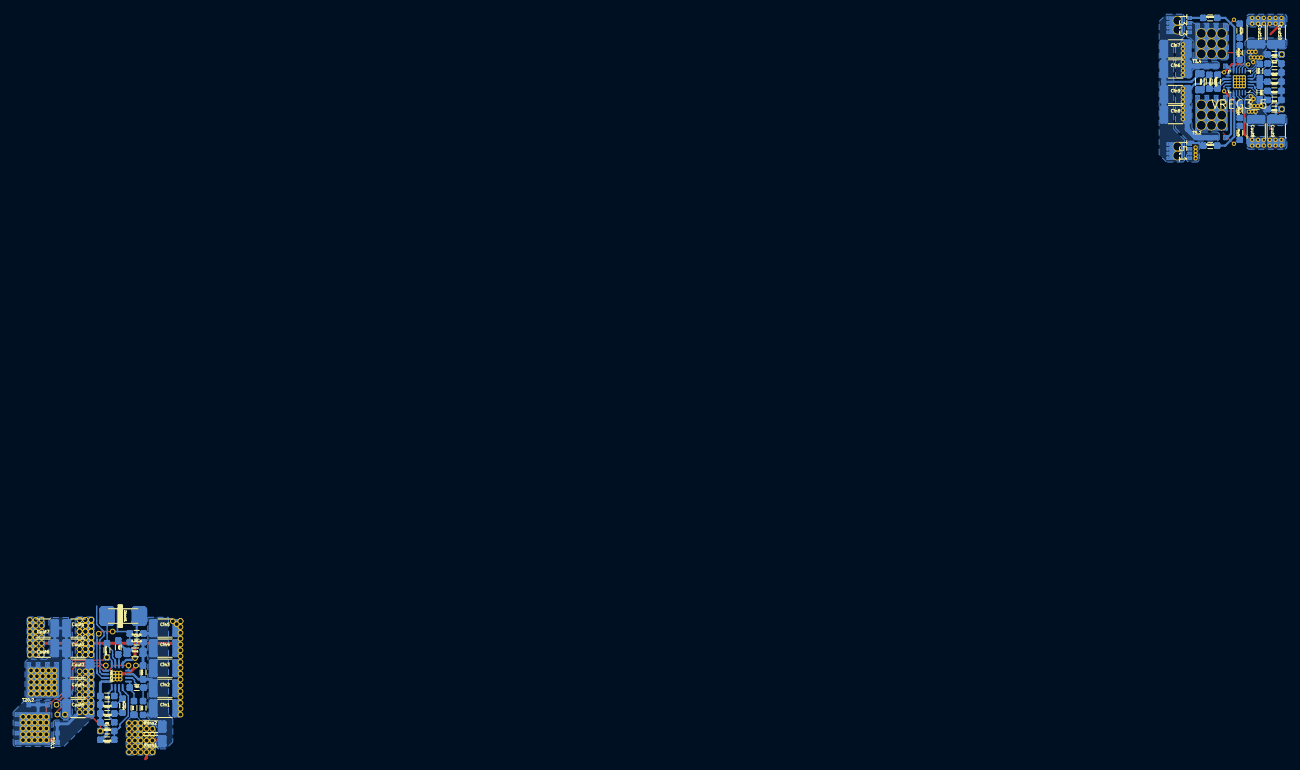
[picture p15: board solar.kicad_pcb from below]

Board: 2 copper layers, 68 parts (65 on the bottom side), 43 nets.

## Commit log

2016-04-05 Adding the first attempts at kicad.
    [solar.kicad_pcb, solar.sch]
2016-04-05 Restarting that project with a clean state to avoid possible hickups from my trials with getting to know Kicad.
    [solar.sch]
2016-04-05 Doing the schematic for VREG20.
    [solar.sch]
2016-04-05 Finished schematic for VREG20.
    [solar.sch]
2016-04-06 Adding more datasheets.
    [solar.kicad_pcb, solar.sch]
2016-04-06 Going to split PGND and AGND.
    [solar.kicad_pcb, solar.sch]
2016-04-06 Added missing resistor.
    [solar.sch]
2016-04-06 Some progress around VREG20.
    [solar.kicad_pcb]
2016-04-07 Working on the VREG20.
    [solar.kicad_pcb]
2016-04-07 Working on the VREG20 (2).
    [solar.kicad_pcb]
2016-04-07 Added the UVLO resistors to VREG20.
    [solar.kicad_pcb, solar.sch]
2016-04-11 Uptdating the footprints with the rounded-edges version.
    [solar.kicad_pcb, solar.sch]
2016-04-11 Changed the footprints to the rounded-corner-version.
    [solar.kicad_pcb]
2016-04-11 Tricky routing above VREG20.
    [solar.kicad_pcb]
2016-04-12 Updating VREG20 to be able to operate from up to 15V and deliver up to 3A (60W).
    [solar.kicad_pcb, solar.sch]
2016-04-12 Fixed wrong pad number in the VREG20 transistors.
    [solar.kicad_pcb, solar.sch]
2016-04-12 WIP: Adding fill polygons.
    [solar.kicad_pcb]
2016-04-12 Regenerated the voltage regulator circuits to allow operation from a 12V car starter battery.
2016-04-14 Adding VREG3_5 and surrounding chicken food.
    [solar.kicad_pcb, solar.sch]
2016-04-14 Beginning to assign footprints to the components of VREG5_3.
    [solar.sch]
2016-10-07 Adding the second VREG
    [solar.sch]
2016-10-07 sorting the parts for the second VREG
    [solar.kicad_pcb, solar.sch]
2016-10-08 Moved the input capacitors
    [solar.kicad_pcb, solar.sch]
2016-10-08 Placing the coils
    [solar.kicad_pcb]
2016-10-08 Added two dummy resistors to avoid via for bridge.
    [solar.kicad_pcb, solar.sch]
2016-10-09 Progress with the layout.
    [solar.kicad_pcb, solar.sch]
2016-10-09 Routing progress.
    [solar.kicad_pcb]
2016-10-09 Some progress. Started to add vias.
    [solar.kicad_pcb]
2016-10-09 Adding polygons.
    [solar.kicad_pcb]
2016-10-09 More polygons.
    [solar.kicad_pcb]
2016-10-10 polys und stitches.
    [solar.kicad_pcb]
2016-10-10 Added solder vias for the big transistors of the buck.
    [solar.kicad_pcb]
2016-10-10 Replacing the big vias with smaller ones to solder like https://www.youtube.com/watch?v=d-f-SBC0GrU
    [solar.kicad_pcb, solar.sch]

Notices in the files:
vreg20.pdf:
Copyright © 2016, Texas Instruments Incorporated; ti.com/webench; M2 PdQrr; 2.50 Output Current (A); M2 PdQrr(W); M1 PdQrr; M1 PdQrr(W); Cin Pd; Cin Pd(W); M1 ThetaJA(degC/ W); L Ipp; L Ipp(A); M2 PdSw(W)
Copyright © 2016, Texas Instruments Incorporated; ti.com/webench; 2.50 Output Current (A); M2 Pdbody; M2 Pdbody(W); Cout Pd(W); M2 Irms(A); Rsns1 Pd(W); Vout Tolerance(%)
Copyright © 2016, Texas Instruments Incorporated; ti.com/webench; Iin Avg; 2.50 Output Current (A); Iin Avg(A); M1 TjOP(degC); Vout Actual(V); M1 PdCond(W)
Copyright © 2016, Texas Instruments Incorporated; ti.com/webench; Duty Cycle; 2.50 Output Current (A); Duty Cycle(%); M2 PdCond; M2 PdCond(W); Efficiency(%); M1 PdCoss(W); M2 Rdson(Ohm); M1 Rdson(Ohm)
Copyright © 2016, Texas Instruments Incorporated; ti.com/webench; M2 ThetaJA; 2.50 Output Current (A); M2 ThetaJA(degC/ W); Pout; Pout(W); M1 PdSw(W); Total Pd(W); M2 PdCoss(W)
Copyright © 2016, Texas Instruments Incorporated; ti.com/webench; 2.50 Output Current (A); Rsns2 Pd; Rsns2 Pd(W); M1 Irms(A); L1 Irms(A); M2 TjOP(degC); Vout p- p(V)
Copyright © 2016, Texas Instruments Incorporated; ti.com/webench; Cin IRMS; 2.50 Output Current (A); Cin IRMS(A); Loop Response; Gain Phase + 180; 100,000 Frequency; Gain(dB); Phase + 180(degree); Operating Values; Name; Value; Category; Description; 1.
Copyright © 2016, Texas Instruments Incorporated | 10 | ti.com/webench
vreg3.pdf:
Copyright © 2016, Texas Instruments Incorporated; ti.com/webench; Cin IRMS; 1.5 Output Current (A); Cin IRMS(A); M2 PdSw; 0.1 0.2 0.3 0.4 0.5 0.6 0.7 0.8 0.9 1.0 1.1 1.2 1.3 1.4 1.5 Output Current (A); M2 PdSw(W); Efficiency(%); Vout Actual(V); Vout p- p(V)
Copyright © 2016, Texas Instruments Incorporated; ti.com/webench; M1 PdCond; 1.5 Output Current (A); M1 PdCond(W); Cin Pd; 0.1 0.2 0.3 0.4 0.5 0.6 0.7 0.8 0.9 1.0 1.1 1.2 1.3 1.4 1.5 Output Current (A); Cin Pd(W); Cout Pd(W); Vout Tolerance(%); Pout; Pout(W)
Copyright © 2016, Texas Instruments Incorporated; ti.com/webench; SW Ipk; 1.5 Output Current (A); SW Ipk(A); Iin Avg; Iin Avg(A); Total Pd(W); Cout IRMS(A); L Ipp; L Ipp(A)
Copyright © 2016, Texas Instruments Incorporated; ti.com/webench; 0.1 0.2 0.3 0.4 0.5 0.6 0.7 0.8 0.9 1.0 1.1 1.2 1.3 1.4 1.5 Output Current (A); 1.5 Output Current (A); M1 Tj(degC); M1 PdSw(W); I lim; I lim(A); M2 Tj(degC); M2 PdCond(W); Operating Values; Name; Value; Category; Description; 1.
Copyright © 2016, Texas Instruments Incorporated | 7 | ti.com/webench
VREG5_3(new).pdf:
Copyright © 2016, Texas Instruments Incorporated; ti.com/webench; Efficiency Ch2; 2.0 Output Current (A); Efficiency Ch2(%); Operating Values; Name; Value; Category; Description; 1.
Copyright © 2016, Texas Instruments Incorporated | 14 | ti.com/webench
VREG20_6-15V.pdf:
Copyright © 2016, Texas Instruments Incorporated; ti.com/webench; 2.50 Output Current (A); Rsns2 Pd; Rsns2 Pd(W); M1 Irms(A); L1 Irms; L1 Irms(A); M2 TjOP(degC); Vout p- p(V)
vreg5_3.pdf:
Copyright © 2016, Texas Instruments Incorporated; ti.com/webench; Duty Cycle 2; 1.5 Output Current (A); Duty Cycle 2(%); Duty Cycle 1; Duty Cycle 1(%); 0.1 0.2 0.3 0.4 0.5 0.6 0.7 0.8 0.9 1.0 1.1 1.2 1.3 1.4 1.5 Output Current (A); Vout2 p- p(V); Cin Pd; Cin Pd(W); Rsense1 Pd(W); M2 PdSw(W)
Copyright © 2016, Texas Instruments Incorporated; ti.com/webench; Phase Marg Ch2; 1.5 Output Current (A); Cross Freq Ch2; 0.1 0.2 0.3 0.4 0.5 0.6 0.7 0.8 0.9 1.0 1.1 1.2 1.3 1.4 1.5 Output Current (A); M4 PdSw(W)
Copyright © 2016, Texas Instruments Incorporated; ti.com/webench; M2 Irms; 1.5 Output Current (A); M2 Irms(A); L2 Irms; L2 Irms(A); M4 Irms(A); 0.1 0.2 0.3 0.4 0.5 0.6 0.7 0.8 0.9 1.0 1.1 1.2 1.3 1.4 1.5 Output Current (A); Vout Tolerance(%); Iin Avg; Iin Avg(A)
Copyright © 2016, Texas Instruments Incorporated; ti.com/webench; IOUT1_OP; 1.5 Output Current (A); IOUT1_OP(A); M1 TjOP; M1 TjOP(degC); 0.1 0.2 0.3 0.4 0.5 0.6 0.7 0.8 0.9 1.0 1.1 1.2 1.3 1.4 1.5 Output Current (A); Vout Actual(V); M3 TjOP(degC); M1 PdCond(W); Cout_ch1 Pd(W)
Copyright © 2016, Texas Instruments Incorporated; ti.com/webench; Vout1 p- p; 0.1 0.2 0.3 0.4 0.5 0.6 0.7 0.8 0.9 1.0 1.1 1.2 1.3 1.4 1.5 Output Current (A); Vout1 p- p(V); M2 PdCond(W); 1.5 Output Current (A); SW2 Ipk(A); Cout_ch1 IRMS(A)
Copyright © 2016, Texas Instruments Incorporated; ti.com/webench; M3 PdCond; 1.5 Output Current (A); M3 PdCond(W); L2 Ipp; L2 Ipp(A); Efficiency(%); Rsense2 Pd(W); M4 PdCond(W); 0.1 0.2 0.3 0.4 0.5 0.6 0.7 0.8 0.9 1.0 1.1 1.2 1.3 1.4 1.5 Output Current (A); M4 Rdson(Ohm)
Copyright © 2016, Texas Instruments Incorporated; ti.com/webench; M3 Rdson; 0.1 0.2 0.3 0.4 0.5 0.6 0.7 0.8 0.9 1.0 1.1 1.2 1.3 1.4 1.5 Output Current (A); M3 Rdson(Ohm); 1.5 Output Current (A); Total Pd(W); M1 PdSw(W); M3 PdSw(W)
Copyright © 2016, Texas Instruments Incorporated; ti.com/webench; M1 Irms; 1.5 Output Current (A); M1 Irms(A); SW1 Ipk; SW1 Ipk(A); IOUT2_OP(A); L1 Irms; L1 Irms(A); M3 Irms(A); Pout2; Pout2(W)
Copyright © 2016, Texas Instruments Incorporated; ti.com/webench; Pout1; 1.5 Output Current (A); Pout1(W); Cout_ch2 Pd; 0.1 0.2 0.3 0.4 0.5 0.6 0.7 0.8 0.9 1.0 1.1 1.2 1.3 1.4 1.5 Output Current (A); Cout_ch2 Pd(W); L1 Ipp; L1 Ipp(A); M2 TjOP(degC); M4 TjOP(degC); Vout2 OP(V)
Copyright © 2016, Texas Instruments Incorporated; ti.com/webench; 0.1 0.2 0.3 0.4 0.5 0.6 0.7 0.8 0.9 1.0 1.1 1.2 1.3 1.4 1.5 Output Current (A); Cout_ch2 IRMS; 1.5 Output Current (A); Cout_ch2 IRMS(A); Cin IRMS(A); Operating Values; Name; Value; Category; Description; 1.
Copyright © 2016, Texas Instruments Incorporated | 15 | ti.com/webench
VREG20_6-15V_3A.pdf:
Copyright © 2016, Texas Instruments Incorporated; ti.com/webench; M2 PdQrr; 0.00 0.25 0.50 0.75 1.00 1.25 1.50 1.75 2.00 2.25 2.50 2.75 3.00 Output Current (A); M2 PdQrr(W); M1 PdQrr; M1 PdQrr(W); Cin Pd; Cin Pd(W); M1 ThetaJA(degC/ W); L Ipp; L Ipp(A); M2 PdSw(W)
